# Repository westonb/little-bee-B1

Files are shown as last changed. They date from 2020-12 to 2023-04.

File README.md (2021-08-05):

# Little Bee B1 - A high performance current & magnetic field probe
**Operating Instructions are located in the [getting-started](getting-started/README.md) folder**

The Little Bee B1 is an open source magnetic field and current probe based on an Anisotropic Magneto-Resistive (AMR) magnetic sensor.
It directly senses magnetic fields and measures current with a current sensing attachment consisting of a gapped ferrite toroid that is placed around a wire, establishing a fixed relation between the current in the wire and magnetic field the sensor is subject to.

The probe is capable of sensing DC currents and has a high frequency -3dB bandwidth in excess of 10Mhz. Typical specifications for current sensing are a +/- 5A range, and a 3mA RMS noise floor. For magnetic field sensing the probe has a +/- 6 gauss range. It is compatible with any 1M ohm input oscilloscope and is powered by a single AA battery. The probe uses a PIC microcontroller to automatically zero the sensor and to provide adjustable gain and bandwidth.

All project source files are in this repository and the project currently has a CrowdSupply [campaign](https://www.crowdsupply.com/weston-braun/little-bee)
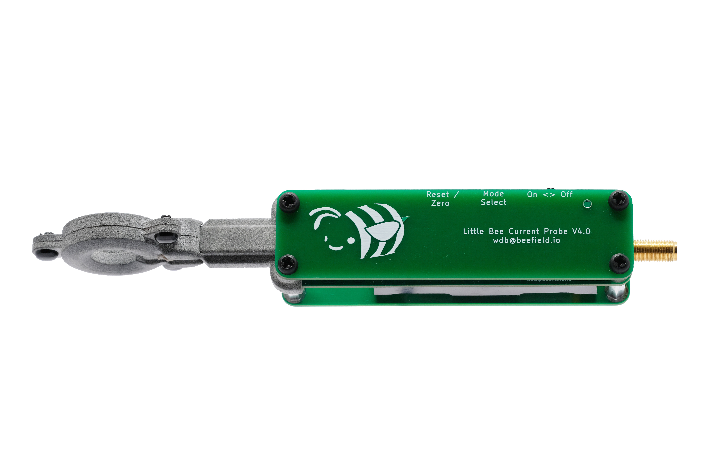
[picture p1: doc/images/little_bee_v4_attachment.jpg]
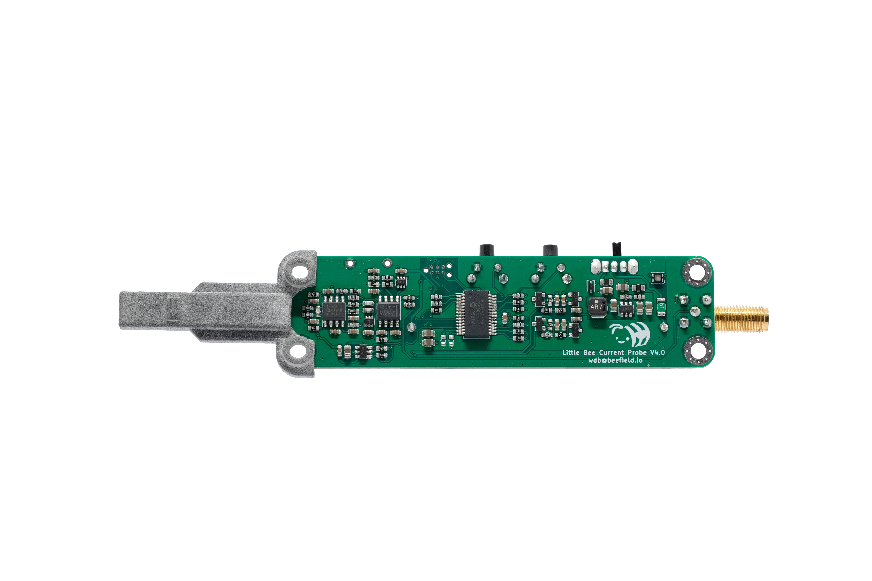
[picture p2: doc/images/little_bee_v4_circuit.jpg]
 

### Typical Electrical Performance

#### Current sensing

- **Bandwidth**: DC - 10 MHz
- **Sensitivity**: 0.25 Volts/Amp
- **Max Current**: +/- 5 A
- **Noise**
    - 3 mA RMS at 10 MHz bandwidth
    - 2 mA RMS at 1 MHz bandwidth
- **DC Accuracy**: +/- 15%
- **Insertion Impedance**: 100 nH in parallel with 70 Ohms

#### Magnetic Field Sensing

- **Bandwidth**: DC - 10 MHz
- **Sensitivity**: 0.2 Volts/Gauss
- **Max Field**: +/- 6 Gauss
- **Noise**
    - 4mG RMS at 10 MHz bandwidth
    - 2.5mG RMS at 1 MHz bandwidth

## Operation
Connect the Little Bee to any oscilloscope with a SMA-BNC cable. When the probe is powered on it automatically zeros and starts in the high bandwidth and low gain mode. Tapping the "Mode Select" button will cycle through the bandwidth and gain options, which are indicated by the LED color.

The probe should be re-zeroed after switching modes. This is accomplished by pressing and holding the "zero/reset" button for at least one second before releasing. The LED will blink once when the button is first pressed and a second time when the zeroing operation is done.

When the sensor is exposed to an excessive magnetic field, or excessive current when the current sensing attachment is used, the sensor will be demagnetized and need to be reset for normal operation. For on axis fields the probe can detect this and will turn the indicator light red.
Off axis fields, which can occur when the probe is used for magnetic field sensing, can exceed the sensor limit without being detected. This will result a loss of sensitivity and noticeable distortion in the sensed waveforms.  
The sensor can be reset and normal operation restored without impacting the zeroing of the probe by tapping the "zero/reset" button, which will briefly flash the indicator light.

If the probe senses a low battery that will inhibit normal operation the indicator light will flash red. An alkaline AA battery should provide around 4 hours of battery life.

### Current Sensing
Current sensing is achieved with the current sensing attachment, which clips on to the tip of the probe. The current sensing attachment uses a ferrite core to translate the current flowing in to a wire into a known magnetic field strength.
A wire can be threaded through the current sensing attachment or the current sensing attachment can be slipped over a wire before being clipped on. With the logo and writing on the Little Bee facing the user, a wire carrying current away from the user will be read as a positive current.

The location of the wire within the current sensing attachment has some impact on the sensitivity of the probe due to the magnetic field in generates. It is recommended to keep the wire on the opposite side of the sensing tip within the aperture of the current sensing attachment.

For higher resolution when measuring low currents, multiple turns of the wire can be made through the aperture of the current sensing attachment. The final sensitivity will be the set sensitivity times the number of turns.

Tapping the "Mode Select" button will cycle through the bandwidth and gain options, which are indicated by the LED color:

| LED Color | Mode |
|---|---|
| Green | 10MHz bandwidth 0.25V/A |
| Yellow | 1MHz bandwidth 0.25V/A  |
| Blue | 10MHz bandwidth 1V/A |
| Teal | 1MHz Bandwidth 1V/A |

The gain of the probe can be adjusted with the labeled trimmer resistor on the PCB. Units are shipped calibrated to the above gains.

### Magnetic Field Sensing
The magnetic sensor is located approximately 1.0mm offset from the tip of the probe. The Little Bee will measure a magnetic field entering perpendicular to the top of the probe as a positive voltage. To measure the magnetic field emitted by a PCB trace the probe should be placed perpendicular to the PCB with the long direction of the tip parallel to the trace.

The earth's magnetic field is typically between 0.3 - 0.6 Gauss, depending on geographic location. This is well within the sensing range of the probe. Additionally, large ferrous objects and transformers can emit stray magnetic fields. It is recommended the Little Bee is zeroed while holding it in the orientation used for taking measurements to reduce the error introduced by stray magnetic fields.

The gain of the probe is calibrated based on measurements with the current sensing attachment, so the true sensitivity will depend on the tolerance current sensing attachment. The nominal sensitivities are:

| LED Color | Mode |
|---|---|
| Green | 10MHz bandwidth 0.2 V/Gauss  |
| Yellow | 1MHz bandwidth 0.2 V/Gauss |
| Blue | 10MHz bandwidth 0.8 V/Gauss  |
| Teal | 1MHz Bandwidth 0.8 V/Gauss |

## Hardware
The kicad PCB files are in the [PCB](pcb/) directory and the [schematic](doc/current-sense.pdf) is in the doc directory.

## Firmware
The Little Bee uses a PIC16 microcontroller to automatically zero the probe and control gain and bandwidth switching. The firmware is built with the
MPLAB X IDE and the complete project is in the [firmware](firmware) directory

## Open Source
This work is licensed under a
[Creative Commons Attribution-ShareAlike 4.0 International License][cc-by-sa].

[][cc-by-sa]

[cc-by-sa]: http://creativecommons.org/licenses/by-sa/4.0/
[cc-by-sa-image]: https://licensebuttons.net/l/by-sa/4.0/88x31.png
[cc-by-sa-shield]: https://img.shields.io/badge/License-CC%20BY--SA%204.0-lightgrey.svg

## Demos
### Sensing the AC line current into a switch-mode power supply


### Sensing the magnetic field from an inductor


### Example Waveforms
Yellow Waveform: Little Bee B1

Green Waveform: Tektronix CT-2 Current Transformer
#### Ramp
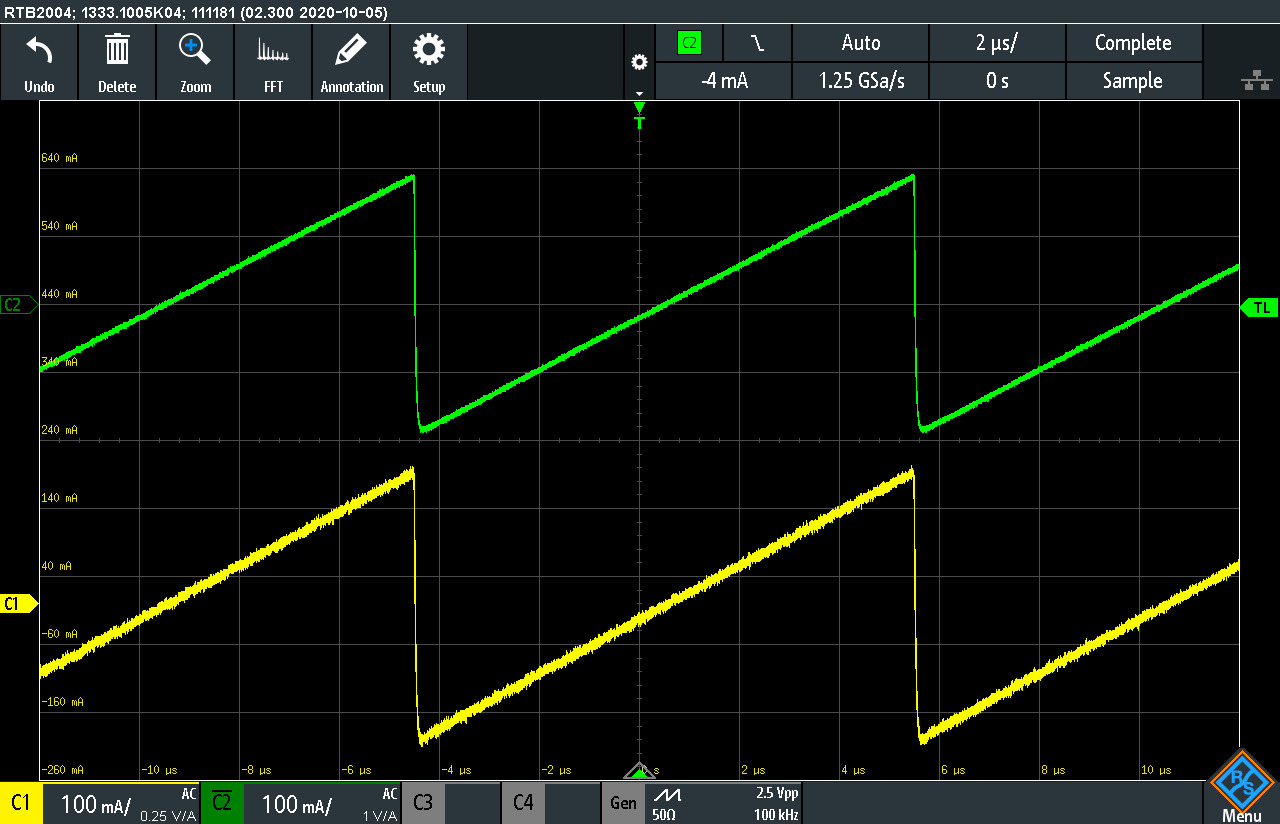
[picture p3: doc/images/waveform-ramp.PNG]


#### SinC
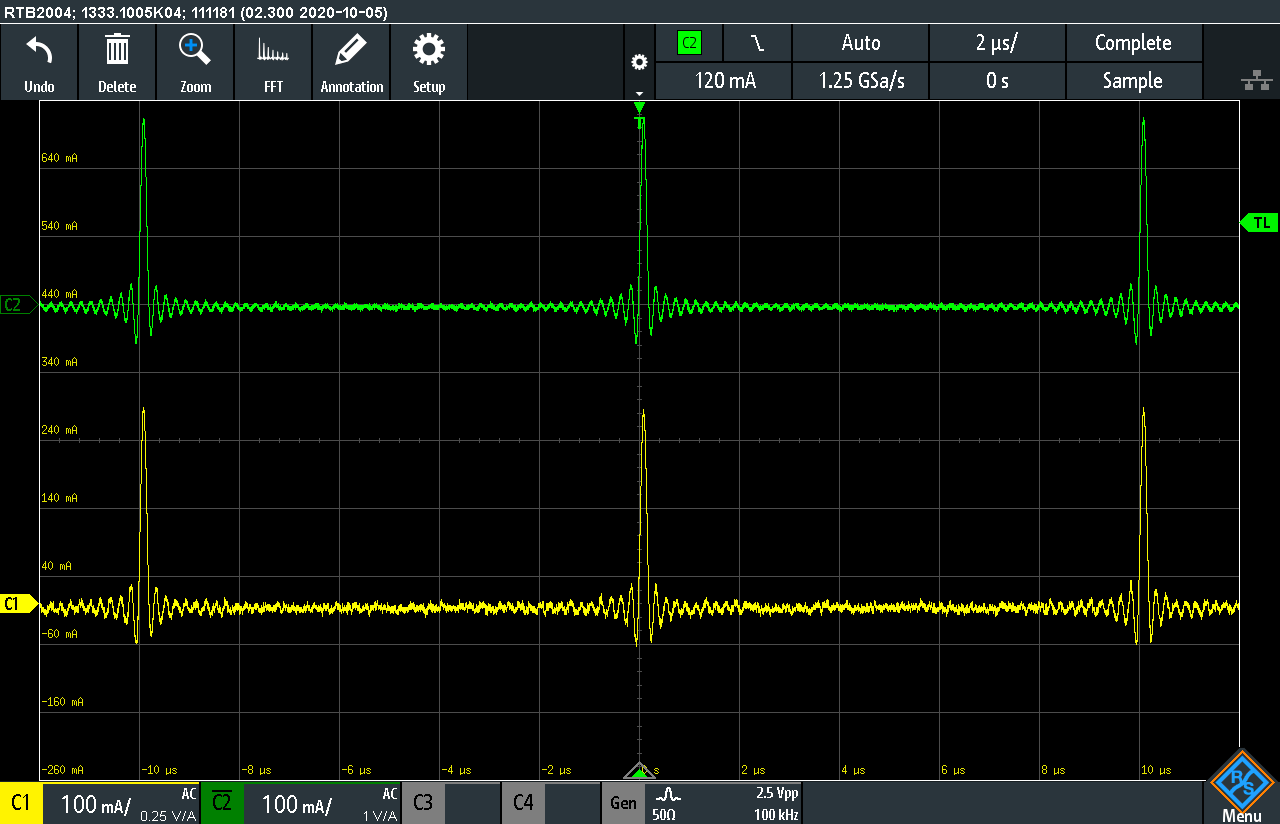
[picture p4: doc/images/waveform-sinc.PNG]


#### Square Wave (Low Current)
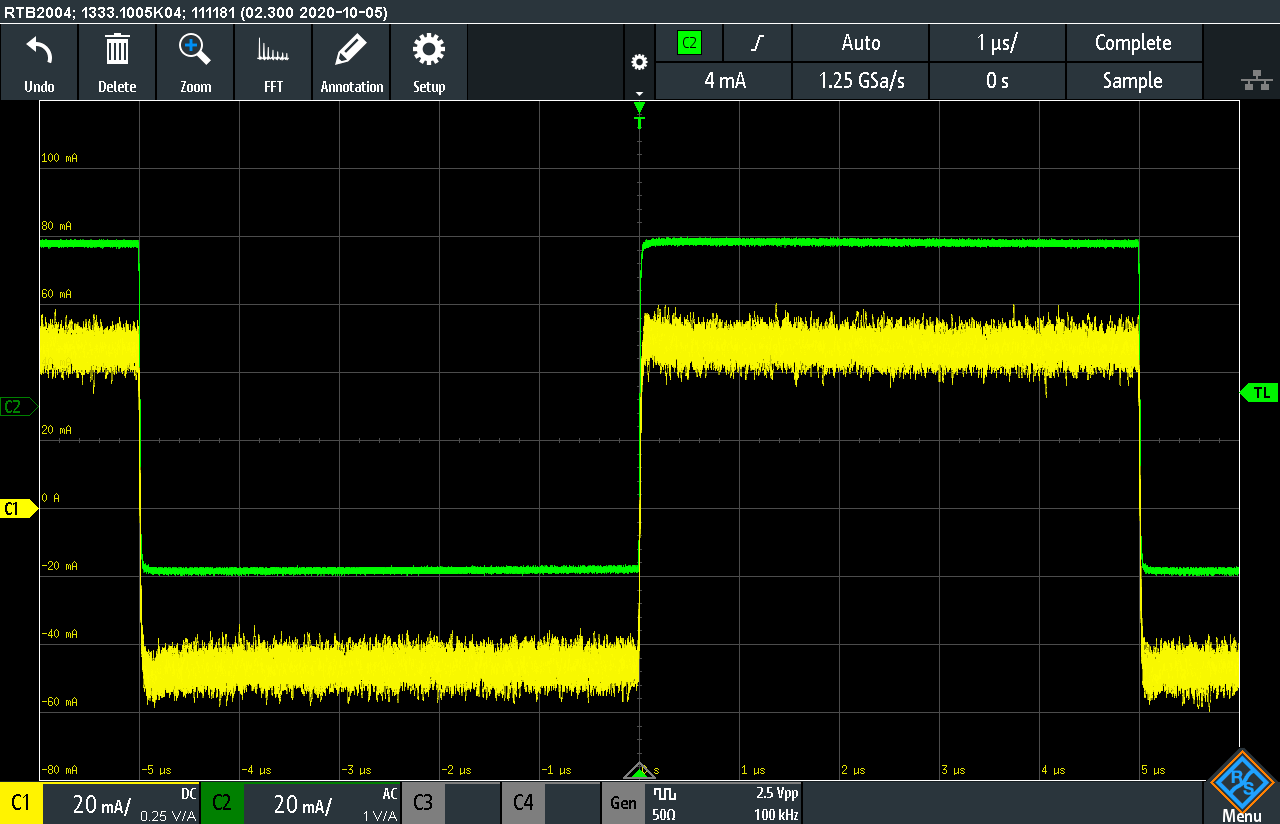
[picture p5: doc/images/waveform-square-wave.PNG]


#### Noise Floor
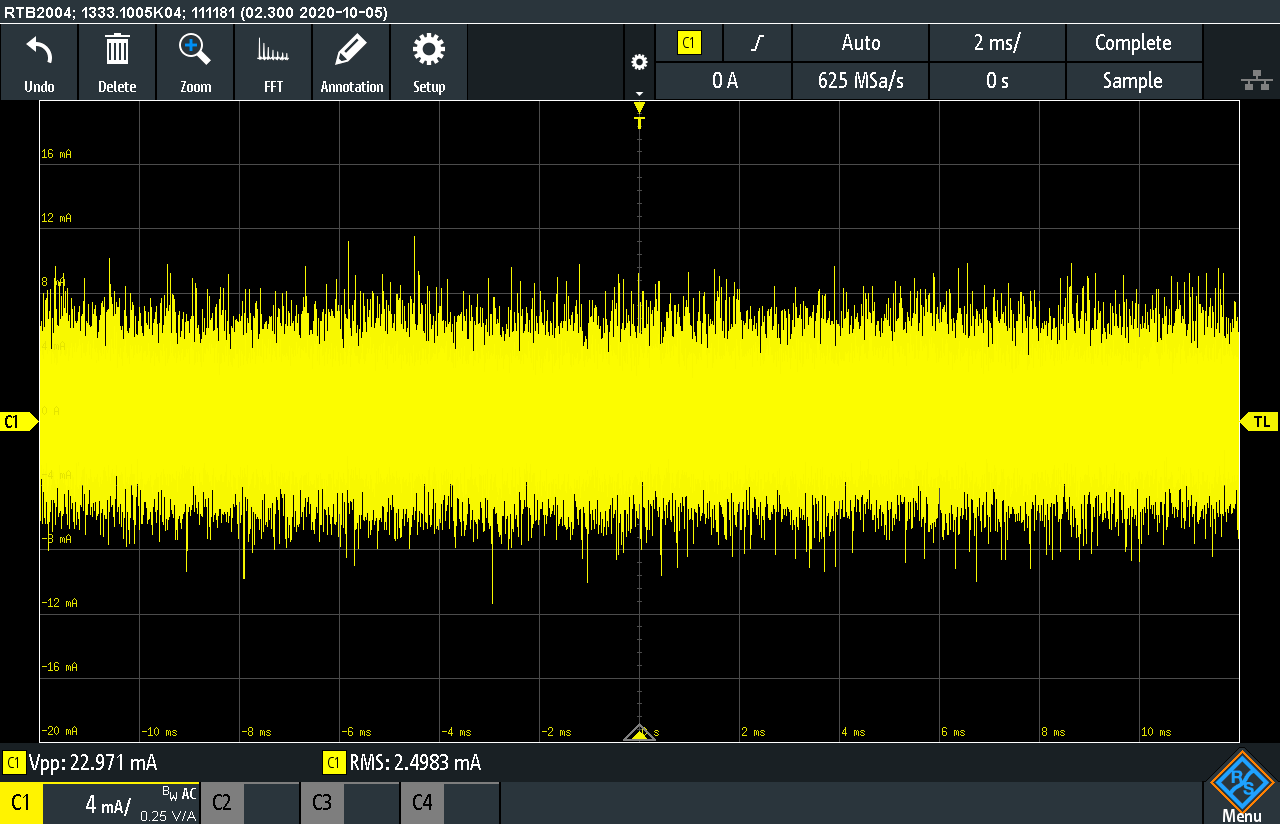
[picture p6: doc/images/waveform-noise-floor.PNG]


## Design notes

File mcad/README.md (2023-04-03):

# Mechanical Parts
Finished probe uses 2x of the ring cover STL and 1x of the tip cover. 
Bottom PCB cover is held in place with 4x M3-16 threaded standoffs. 
Top PCB cover is held in place with 2x 5mm OD 4mm long unthreaded standoffs.

# Flux Concentrator 
Fair-Rite 5943001301 core with a nominal gap of 8.25mm and parallel faces. Ring cover held into place with 3x 0.122" hole size plastic rivets, McMaster-Carr P/N 91020A120

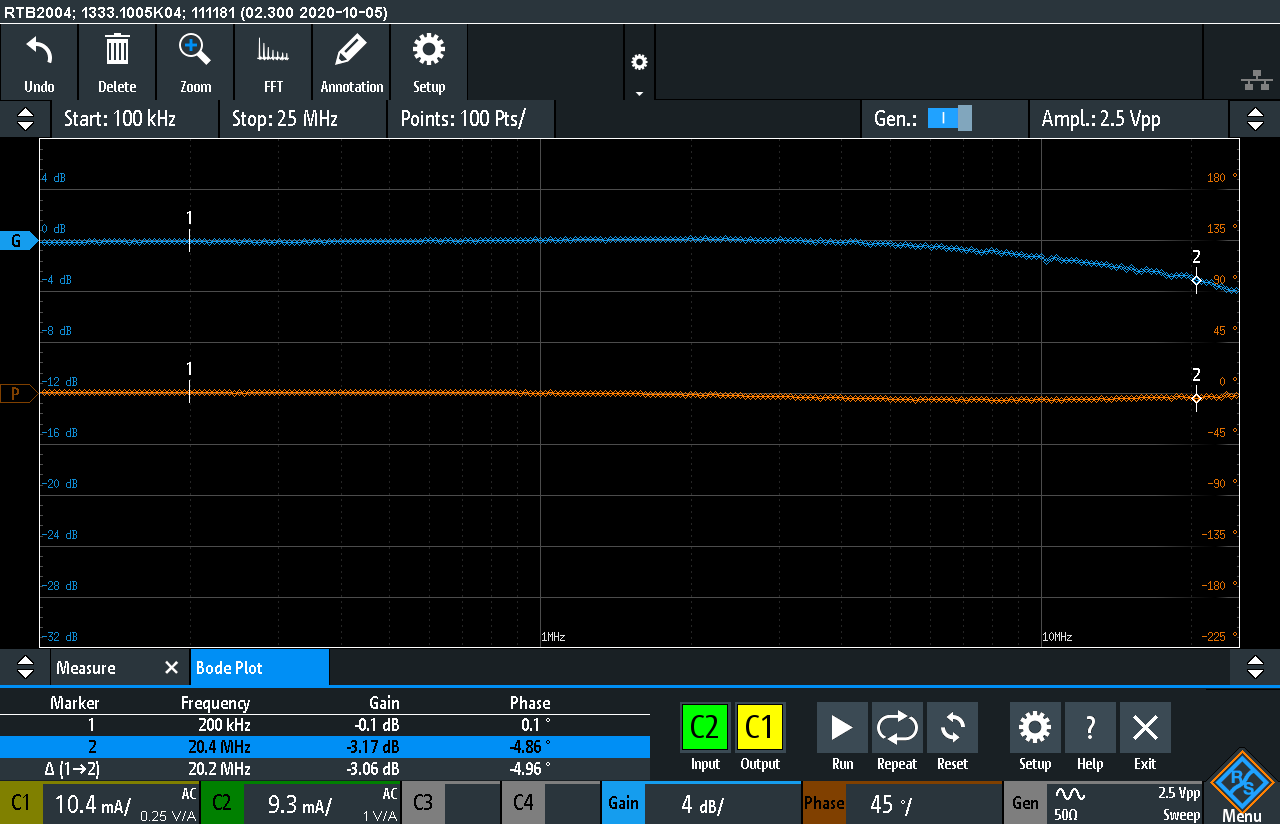
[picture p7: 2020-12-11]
doc/images/bode-highBW-low-gain.PNG

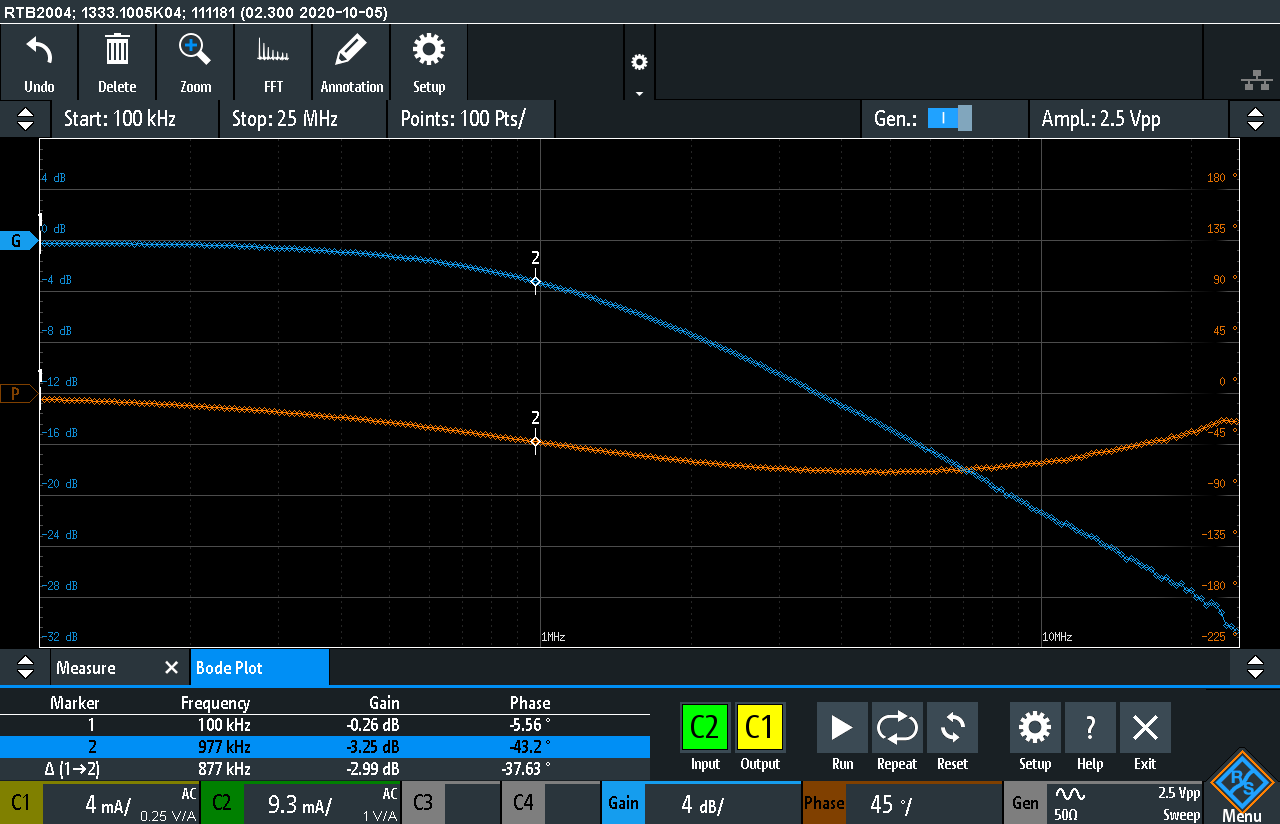
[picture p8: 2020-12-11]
doc/images/bode-lowBW-low-gain.PNG

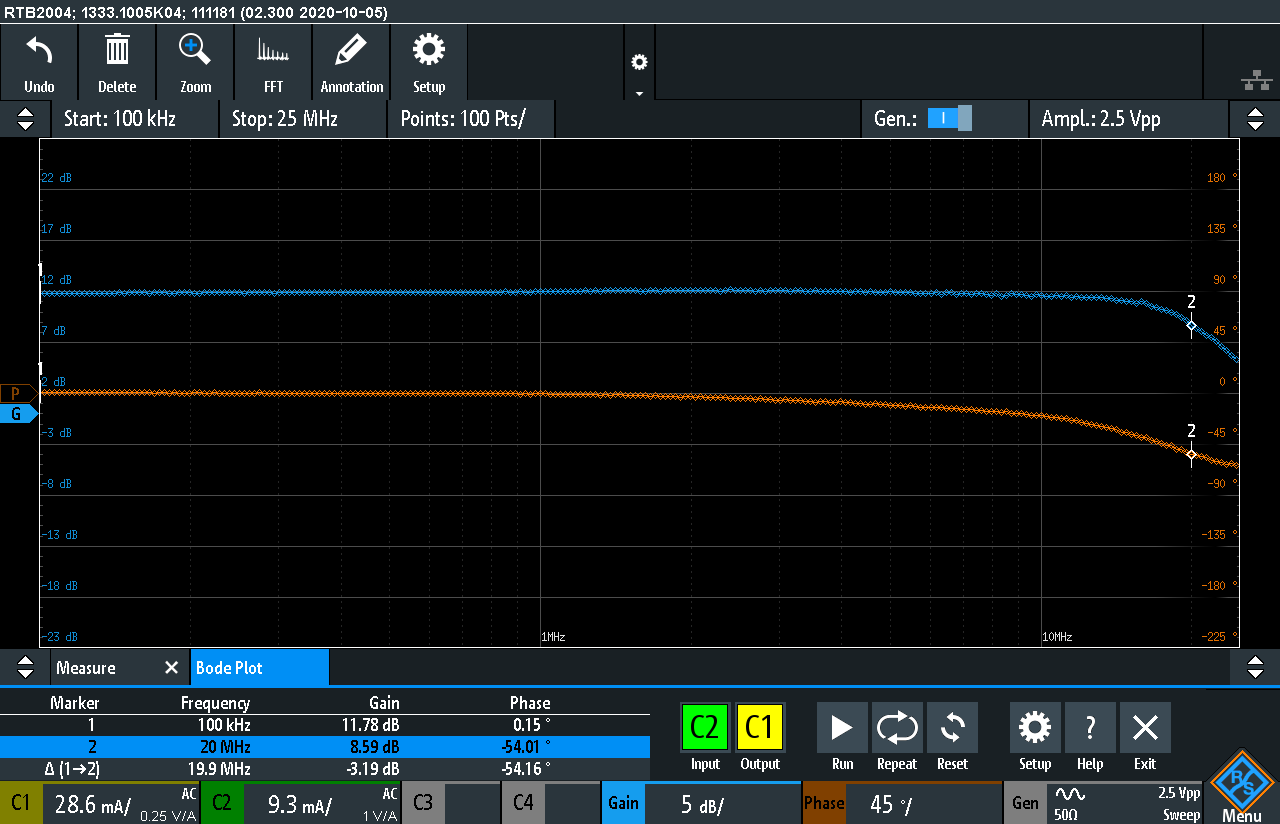
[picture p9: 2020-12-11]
doc/images/bode-highBW-high-gain.PNG

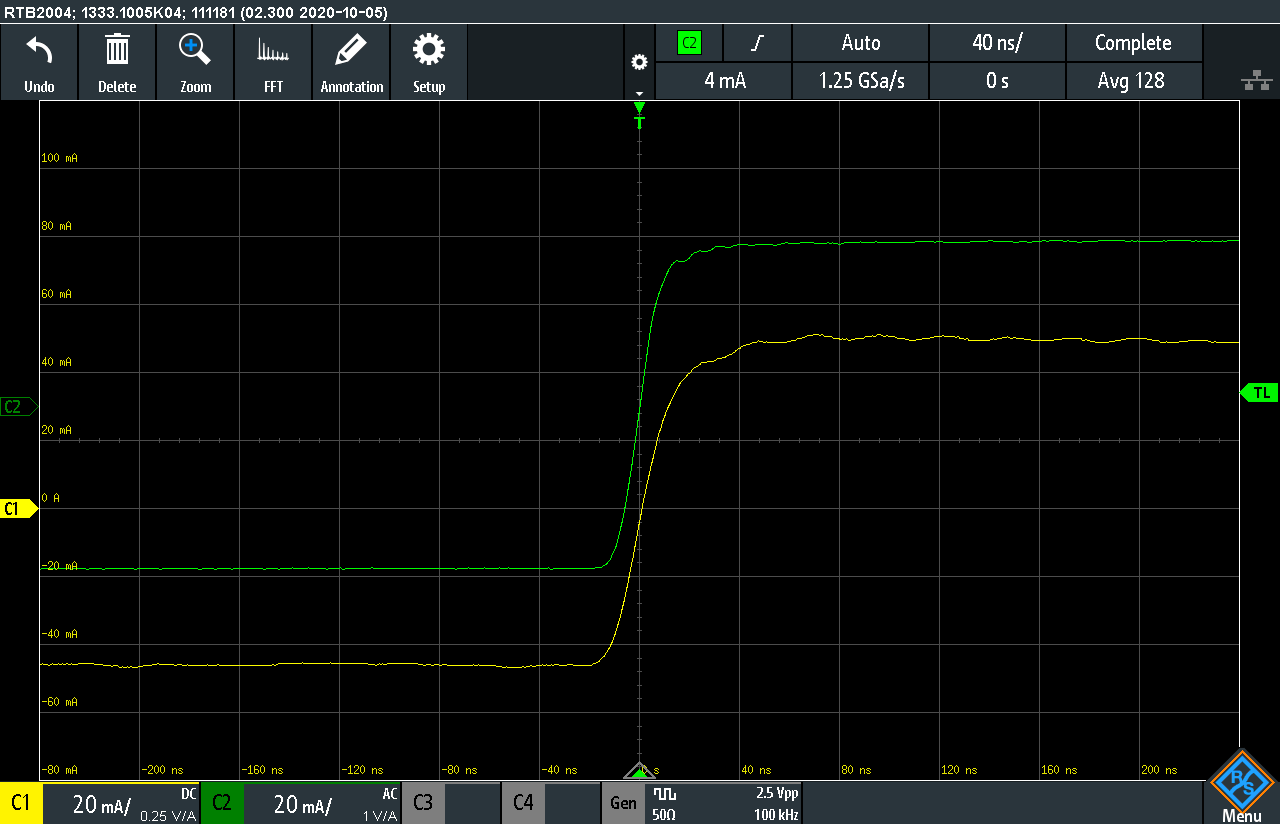
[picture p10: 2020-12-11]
doc/images/waveform-fast-edge.PNG

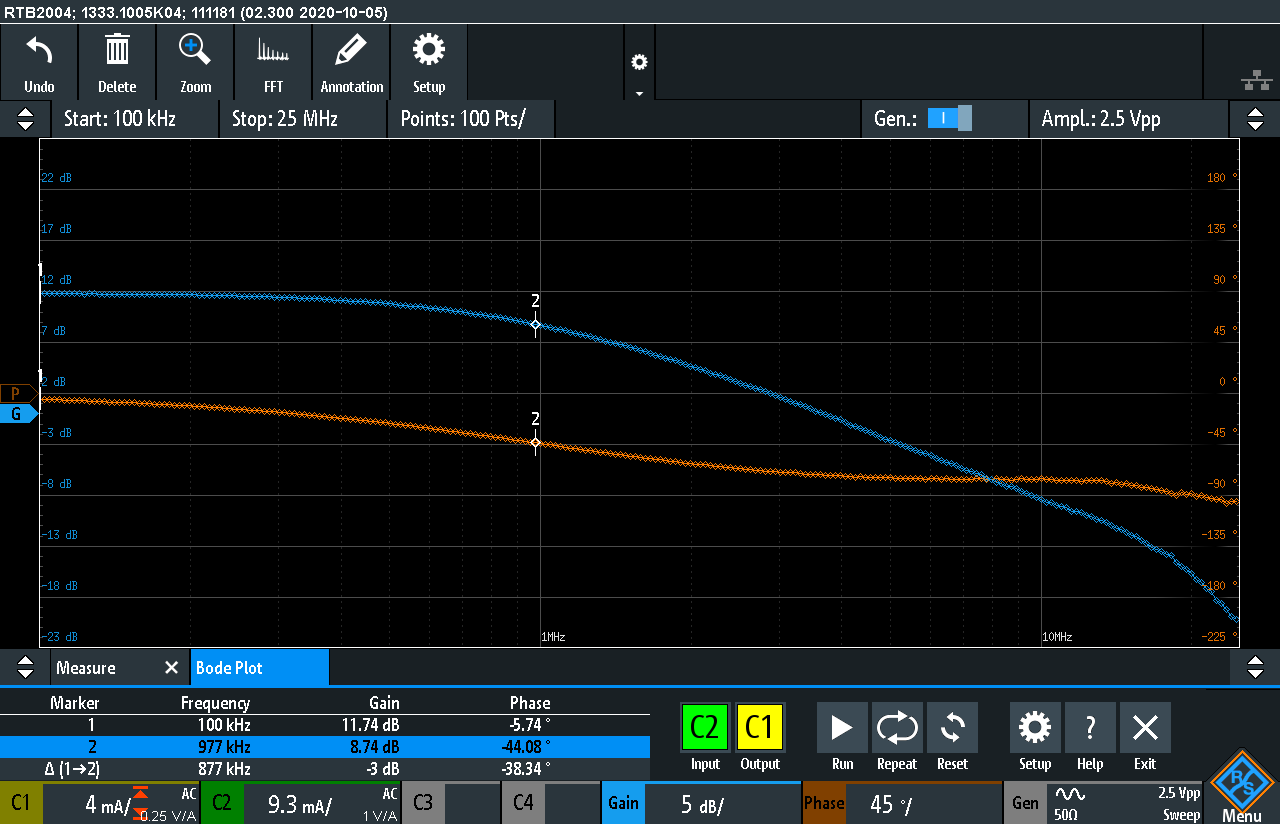
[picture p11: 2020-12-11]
doc/images/bode-lowBW-high-gain.PNG

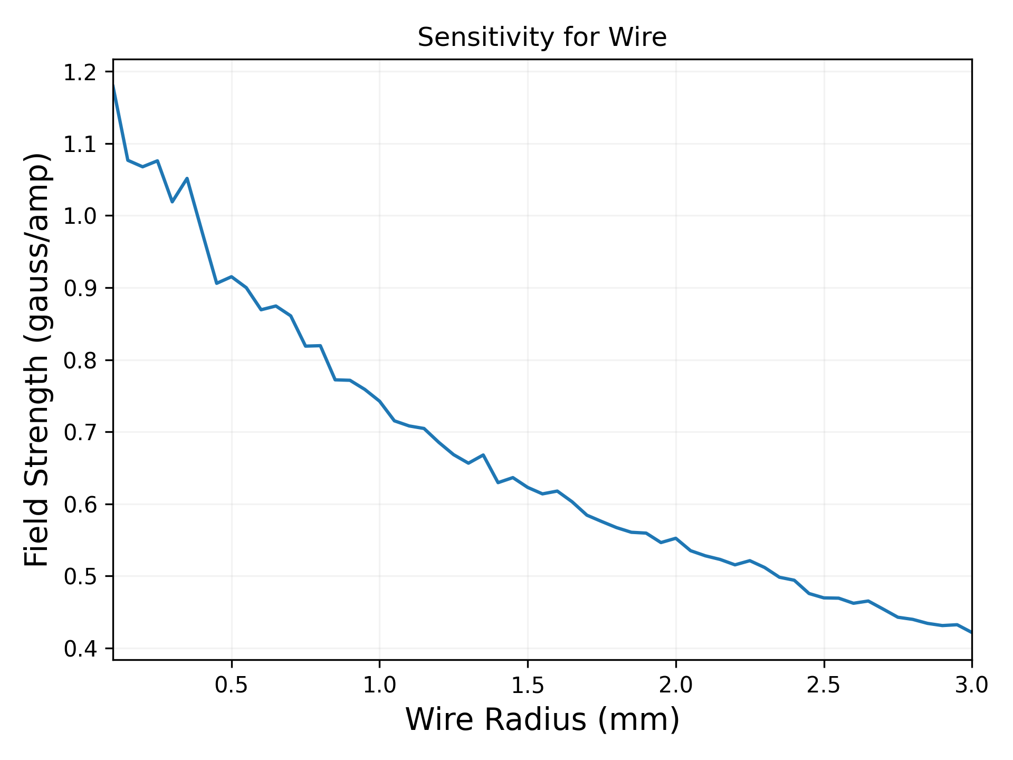
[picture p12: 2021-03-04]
modeling/wire_radius_plt.png

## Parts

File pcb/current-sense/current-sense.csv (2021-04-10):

Ref | Qty | Value | Footprint | Description | MPN
C1, C13, C14, C17, C20, C21, C22, C33, | 8 | 22u | Capacitor_SMD:C_0805_2012Metric | Unpolarized capacitor | LMK212BBJ226MG-T
C2, C3, C5, C8, C9, C10, C11, C12, C15, C16, C19, C23, C25, C26, C27, C28, C29, C30, C31, C32, C34, | 21 | 1u | Capacitor_SMD:C_0603_1608Metric | Unpolarized capacitor | CL10B105KO8NNNC
C4, | 1 | 10p | Capacitor_SMD:C_0603_1608Metric | Unpolarized capacitor | CL10C100CB8NNNC
C6, | 1 | 22p | Capacitor_SMD:C_0603_1608Metric | Unpolarized capacitor | CL10C220JB8NFNC
C7, | 1 | 750p | Capacitor_SMD:C_0603_1608Metric | Unpolarized capacitor | CC0603JRNPO9BN751
C18, C24, C35, C36, | 4 | DNP | Capacitor_SMD:C_0603_1608Metric | Unpolarized capacitor
D1, | 1 | LED_ARGB | LED_SMD:LED_Cree-PLCC4_2x2mm_CW | RGB LED, anode/red/green/blue | CLMVC-FKA-CL1D1L71BB7C3C3
D2, D3, | 2 | BAT54SLT1G | Package_TO_SOT_SMD:SOT-23 | Dual Schottky diode, anode/cathode/center | BAT54SLT1G
D4, | 1 | NTSAF345T3G | Diode_SMD:D_SMA | Diode | NTSAF345T3G
FB1, FB2, | 2 | Ferrite_Bead_Small | Inductor_SMD:L_0805_2012Metric | Ferrite bead, small symbol | BKP2125HS600-T
J1, J2, J4, J5, | 4 | M3 | wbraun_smd:M3-tight-fit-socket-head | mounting hole
J3, | 1 | Tag Connect | wbraun_smd:TC2030-IDC-NL | Generic connector, double row, 02x03, odd/even pin numbering scheme (row 1 odd numbers, row 2 even numbers), script generated (kicad-library-utils/schlib/autogen/connector/)
J6, | 1 | Conn_Coaxial | Connector_Coaxial:SMA_Molex_73251-2200_Horizontal | coaxial connector (BNC, SMA, SMB, SMC, Cinch/RCA, ...) | 619540-1
J7, | 1 | AA Holder | wbraun_smd:AA-2460 | Generic connector, single row, 01x02, script generated (kicad-library-utils/schlib/autogen/connector/) | 2460
J8, | 1 | DNP | Connector_JST:JST_XH_B2B-XH-A_1x02_P2.50mm_Vertical | Generic connector, single row, 01x02, script generated (kicad-library-utils/schlib/autogen/connector/) | B2B-XH-A(LF)(SN)
L1, | 1 | 4.7u | wbraun_smd:L_VLCF4020 | Inductor | VLCF4020T-4R7N1R2
NT1, | 1 | Net-Tie_2 | wbraun_smd:NET_TIE | Net tie, 2 pins
Q1, | 1 | FDC6327C | Package_TO_SOT_SMD:TSOT-23-6 | 4.6A/-3.2A Id, 20V Vds, Complementary pair enhancement mode P-Channel and N-Channel MOSFET, TSOT-23-6 | FDC6327C
R1, R2, R10, R11, R23, R24, R25, R27, R28, | 9 | 4.7k | Resistor_SMD:R_0603_1608Metric | Resistor | RC0603FR-074K7L
R3, R7, | 2 | 105 | Resistor_SMD:R_0603_1608Metric | Resistor | RC0603FR-07105RL
R4, R13, | 2 | 220 | Resistor_SMD:R_0603_1608Metric | Resistor | RC0603FR-07220RL
R5, R6, R20, | 3 | 43 | Resistor_SMD:R_0603_1608Metric | Resistor | RC0603FR-0743RL
R8, R9, R12, R15, R17, R19, | 6 | 1.43k | Resistor_SMD:R_0603_1608Metric | Resistor | RC0603FR-071K43L
R14, R22, R32, R33, R34, R35, R40, | 7 | 32.4k | Resistor_SMD:R_0603_1608Metric | Resistor | RC0603FR-0732K4L
R16, | 1 | 470 | Resistor_SMD:R_0603_1608Metric | Resistor | RC0603FR-07470RL
R18, | 1 | 0 | Resistor_SMD:R_0603_1608Metric | Resistor | RC0603JR-070RL
R21, | 1 | 102k | Resistor_SMD:R_0603_1608Metric | Resistor | RMCF0603FT102K
R26, R36, R37, | 3 | 4.7 | Resistor_SMD:R_0603_1608Metric | Resistor | RC0603FR-074R7L
R29, R38, R39, | 3 | DNP | Resistor_SMD:R_0603_1608Metric | Resistor
R30, R31, | 2 | 130 | Resistor_SMD:R_0603_1608Metric | Resistor | RC0603FR-07130RL
RV1, | 1 | 2k | wbraun_smd:TRIMMER_PVG3A | Trim-potentiometer, US symbol | PVG3A202C01R00
SW1, SW2, | 2 | SW_Push | wbraun_smd:SW_Tactile_SPST_Angled_PTS645Vx58-2LFS | Push button switch, generic, two pins | PTS645VL58-2 LFS
SW3, | 1 | SW_SPDT | wbraun_smd:SW_EG1247_SPDT_Angled | Switch, single pole double throw | EG1247
U1, | 1 | HMC1041Z | wbraun_smd:HMC1041Z | AMR Magnetic Sensor | HMC1041Z-TR
U2, | 1 | AD8129 | Package_SO:SOIC-8_3.9x4.9mm_P1.27mm | Differential Receiver | AD8129ARZ
U3, U6, | 2 | TMUX1219 | Package_TO_SOT_SMD:SOT-363_SC-70-6 | SPDT Analog Switch | TMUX1219DCKR
U4, | 1 | PIC16F1776-ISS | Package_SO:SSOP-28_5.3x10.2mm_P0.65mm | PIC Microcontroller | PIC16F1776-I/SS
U5, | 1 | TLV3542 | Package_SO:SOIC-8_3.9x4.9mm_P1.27mm |  | TLV3542IDR
U7, | 1 | MCP1640 | Package_TO_SOT_SMD:SOT-23-6 |  | MCP1640BT-I/CHY
U8, U9, | 2 | LM4041LP-ADJ | Package_TO_SOT_SMD:SOT-23 | Adjustable Precision Micropower Shunt Voltage Reference, TO-92 | LM4041CYM3-ADJ-TR

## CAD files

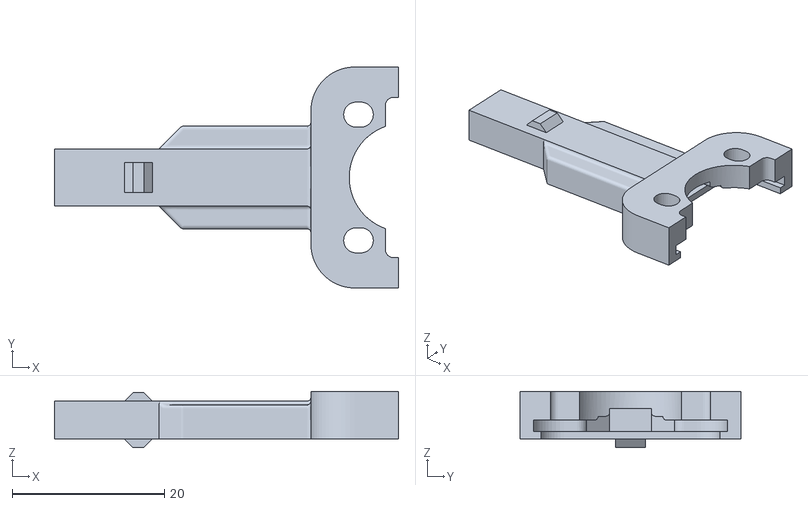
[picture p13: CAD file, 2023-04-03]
mcad/tip-cover_production.stl
45.2 x 29.0 x 7.35

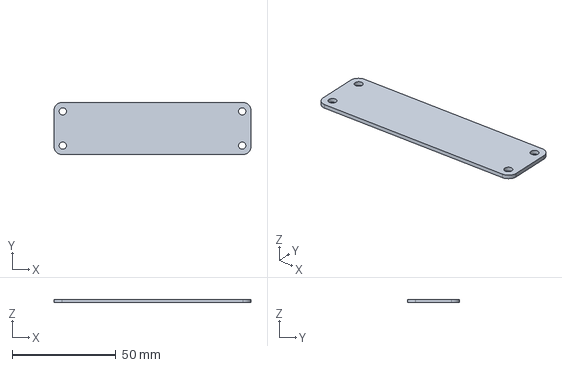
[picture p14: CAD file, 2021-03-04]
pcb/casing_bottom/casing.step
95.0 x 25.0 x 1.60 mm

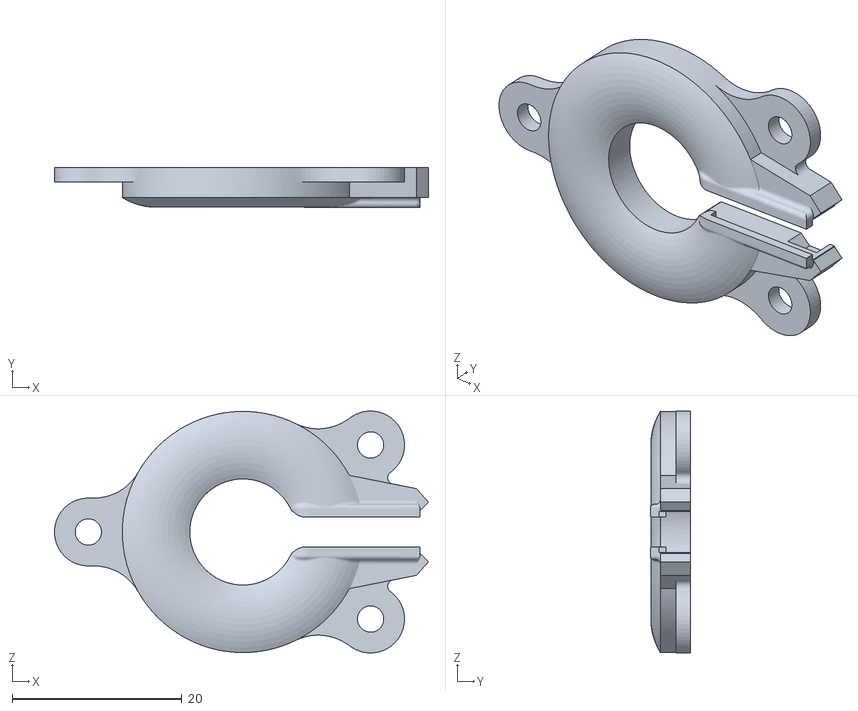
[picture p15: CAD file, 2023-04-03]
mcad/ring_cover_production.stl
44.1 x 4.75 x 28.5

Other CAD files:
pcb/casing_top/casing.step
mcad/casing_top.step

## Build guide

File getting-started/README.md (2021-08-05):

# Little Bee B1 Operating Instructions

## Introduction
The Little Bee is a current and magnetic field probe using an Anisotropic Magneto-Resistive (AMR) magnetic sensor.
Current in a wire can accurately be sensed in a wire with the current sensing attachment.
Without the attachment the Little Bee can be used to directly measure magnetic fields. In the context of circuit debugging this can be used to measure the current waveforms in PCB traces and inductors.  
The Little Bee is powered by a AA battery, with an expected battery life of 4 hours, and connects to any oscilloscope with a 1M Ohm input with a SMA to BNC cable.
The Little Bee has auto zeroing functionality and 4 different gain and bandwidth modes.

## Typical Electrical Performance
All Little Bee units are serialized and the frequency response is characterized in production for the low gain and 10MHz bandwidth mode.
Production data is in the [test-data](../production/test-data) folder in this repo.
Below is a plot of all of the production data.
The outliers are from early production where gain was adjusted after characterization and there was a 20MHz bandwidth limit enabled on the test oscilloscope.
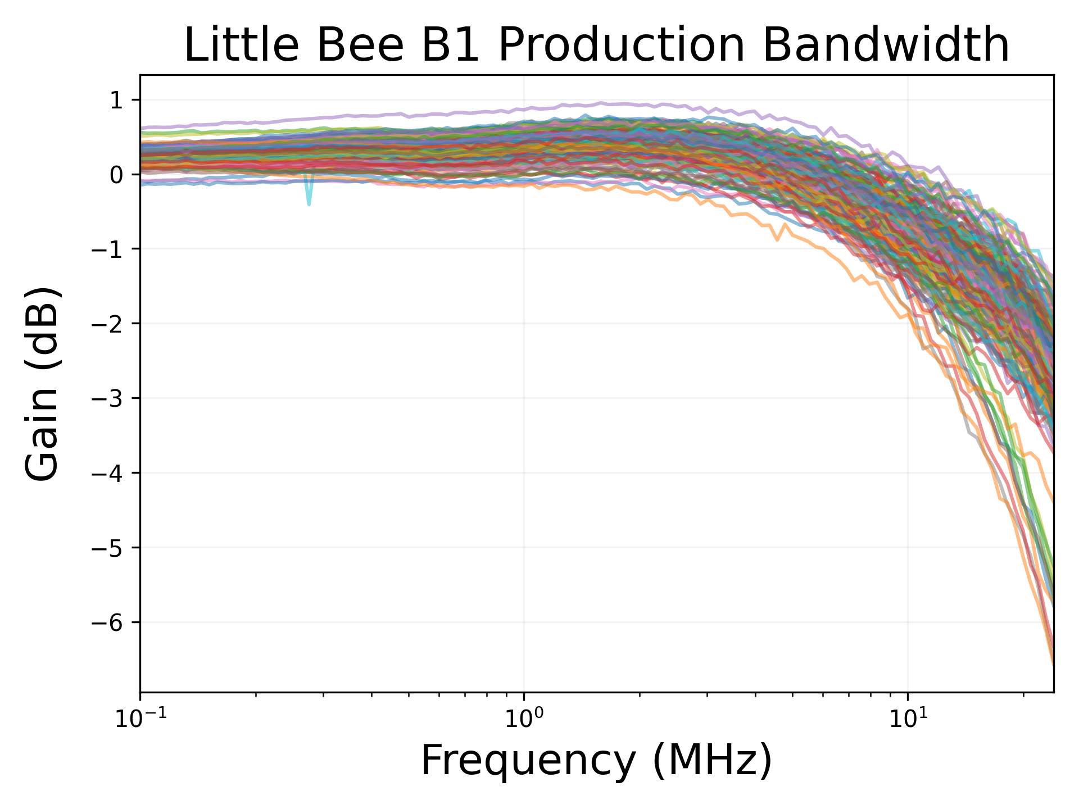
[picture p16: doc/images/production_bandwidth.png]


#### Current sensing

- **Bandwidth**: DC - 10 MHz
- **Sensitivity**: 0.25 Volts/Amp at low gain, 1.00 Volts/Amp at high gain
- **Max Current**: +/- 5 A at low gain, +/- 1.5 A at high gain
- **Noise**
    - 3 mA RMS at 10 MHz bandwidth
    - 2 mA RMS at 1 MHz bandwidth
- **DC Accuracy**: +/- 15%
- **Insertion Impedance**: 100 nH in parallel with 70 Ohms

#### Magnetic Field Sensing

- **Bandwidth**: DC - 10 MHz
- **Sensitivity**: 0.2 Volts/Gauss at low gain, 0.8 Volts/Gauss at high gain
- **Max Field**: +/- 6 Gauss at low gain, +/- 1.8 Gauss at high gain
- **Noise**
    - 4mG RMS at 10 MHz bandwidth
    - 2.5mG RMS at 1 MHz bandwidth

## Operation
### Start Up
When the Little Bee is powered on it will initialize in the low gain and high bandwidth mode and immediately enter the auto-zero routine.
The auto-zero routine takes 3.5 seconds and the LED will blink once when auto-zeroing is finished.
During this period the Little Bee will not respond to repeated button presses.
Once the auto-zero routine is done the Little Bee is ready to use.
The two buttons "Reset/Zero" and "Mode Select" are used to control the functionality of the Little Bee and the color of the status LED is used to indicate the probe status and operating mode.
By holding both buttons down before power is switched on the Little Bee will start up in an absolute field sensing mode until power is cycled.

### Reset and Zero
The "Reset/Zero" button can be used to reset the sensor after exposure to a high magnetic field or to zero the probe in order to remove impacts from ambient magnetic fields for improved accuracy when measuring low currents or magnetic fields.
Tapping the "Reset/Zero" button will reset the sensor.
When the sensor is reset the status LED will flash off and on twice in quick succession.
If the status LED was previously red due to the requirement for a sensor reset, the status LED will return to the normal color after reset.
Resetting the Little Bee sensor has no impact on the zeroing.  

If the "Reset/Zero" button is held for more than 1 second the probe will enter the auto-zero routine, which takes 2 to 4 seconds.
The LED will flash off and on once at the start of the auto-zero routine and once after the auto-zero routine is finished.

Rarely, the auto-zero routine is unable to zero the output due to high ambient magnetic fields.
When this happens the status LED will blink red at the end of the auto-zeroing routine.

### Mode Select
Pressing the "Mode Select" button cycles the Little Bee through the 4 gain and bandwidth modes.
The current mode is indicated by the color of the status LED.
The status LED will cycle in the order of  \[Green, Yellow, Blue, Teal\]  with each press of the "Mode Select" button.

### Status LED
The status LED is used to indicate the gain and bandwidth setting of the Little Bee as well as to indicate error conditions.
The below table details the meaning of each status LED color.

| Status LED Color | Mode |
|---|---|
| Green | 10MHz bandwidth 0.25V/A or 0.2 V/Gauss |
| Yellow | 1MHz bandwidth 0.25V/A or 0.2 V/Gauss |
| Blue | 10MHz bandwidth 1V/A or 0.8 V/Gauss |
| Teal | 1MHz Bandwidth 1V/A or 0.8 V/Gauss |
| Red | Sensor Reset Required |
| Flashing Red | Low Battery |
| Purple | Absolute Field Sensing Mode |

### Current Sensing



The Little Bee is used for current sensing mode by clipping the included current sensing attachment on to the detents on the probe tip and passing a wire though the hole in the current sensing attachment.
To reduce mechanical strain it is recommended to hold the Little Bee by the plastic tip cover when clipping on the current sensing attachment.

The electrical operation of the Little Bee is the same between current sensing and field sensing, the current sensing attachment merely establishes a fixed relationship between the current flowing in the wire and the magnetic field the sensor is exposed to.
The direction of current flow in a wire for a positive output voltage is indicated on the top of the Little Bee.

The location of the wire within the current sensing attachment may cause minor changes in the gain of the probe.
For maximal accuracy it is recommended to prevent the wire from being directly adjacent to the probe tip and instead keep it centered in the middle or at the far end of the current sensing attachment.
When measuring small currents, multiple turns of wire may be made through the center of the current sensing attachment to increase the response.
The current measured by the Little Bee will be the current flowing through the wire multiplied by the number of turns.

The current sensing attachment may have a residual magnetic field and only reduces, but does not eliminate, the influences of external magnetic fields.
To maximize accuracy it is recommended to zero the Little Bee after clipping the current sensing attachment on and placing the Little Bee as part of the test setup.

The magnetic domains in the AMR sensor used in the Little Bee can be mis-aligned by large magnetic fields, leading to incorrect output until the sensor is reset.
With the current sensing attachment, the majority of the magnetic field will be on the sensitive axis of the sensor, which allows the Little Bee to detect this overload condition.
At currents above 6 amps the status LED will turn red, indicating the need for a sensor reset.

### Magnetic Field Sensing



Without the current sensing attachment the Little Bee can be used to directly sense magnetic fields.
Useful applications for this include tracing currents in PCB traces and measuring inductor current waveforms through leakage magnetic fields.
The magnetic field direction for a positive output voltage is marked on the top of the Little Bee and shown below for convenience.

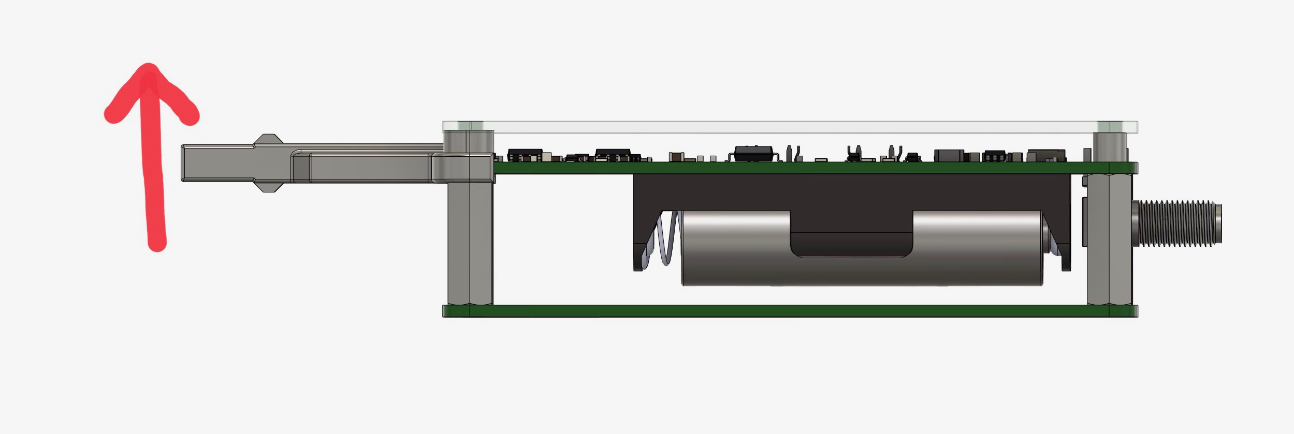
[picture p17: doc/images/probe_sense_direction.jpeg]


This direction means that for checking the current in a PCB trace the body of the Little Bee should be held perpendicular to the PCB with the longer side of the probe tip parallel to the PCB trace.
If trying to measure the current in a PCB trace it is recommended to first calibrate your measurements with a known current flowing through a PCB trace, but for typical PCB geometries the Little Bee response will be around 0.2V/A when the probe is in low gain mode.

Due to the small magnetic fields generated by PCB traces carrying even modest currents, measurements are susceptible to ambient magnetic fields, with the magnetic field strength of the earth being a large contributor.
It is recommended that measurements be taken away from any large iron transformers, motors, or fans, and the Little Bee first be zeroed while being held a few inches above the PCB in the orientation that will be used for probing.

Another difficulty in taking magnetic field measurements is saturating the sensor with excessive magnetic fields.
The sensor can be overloaded, corrupting the output until it is reset, by magnetic fields that are not on the sensitive axis.
This means that, unlike with current sensing, the Little Bee can not always detect when the sensor has been overloaded and requires a reset.
For applications where the magnetic field may be large and it is not necessarily clear what the magnetic field direction is, such as sensing the leakage magnetic fields of inductors and transformers, it is recommended to keep the Little Bee as far back as possible while still getting good readings and to reset the sensor often.

### Absolute Field Sensing Mode  
The absolute field sensing mode is mostly a novelty and debug tool that was added in late development.
If both buttons are held down when the Little Bee is turned on the system will enter absolute field sensing mode until power is cycled and the status LED will turn purple.
In this mode all further button inputs are ignored until power is cycled.

In this mode the sensor sensing polarity is flipped at 55Hz by re-aligning the magnetic domains using the reset circuitry.
This effectively performs signal mixing with the sensor input and a 55Hz signal.
This shifts the sensor DC magnetic field reading to 55Hz while all system offsets stay at DC, allowing the value of the absolute magnetic field strength to be measured as a peak to peak AC value.
This can be used for checking ambient magnetic field strengths, which would otherwise be zeroed out by the probe.
Additionally, with added digital signal processing, this mode can allow for the Little Bee to measure very small magnetic fields.

## Safety
The Little Bee B1 is not CAT rated.
Do not use the Little Bee on un-insulated wires.
The Little Bee is designed for use in a laboratory environment. 

## Improvements
### External Power
Based on user feedback to power the Little Bee with something other than a AA battery, there is an unpopulated footprint for a 2 pin JST-XH connector (part number B2B-XH-A(LF)(SN)).
Through this footprint up to 4.5 volts can be supplied, such as an lithium-ion battery.
If an external power adapter is used it must be low noise and isolated; the SMA ground terminal on the Little Bee is not directly referenced to the negative pin on this terminal.

### Mechanical Case
STL files for a user printable mechanical case for the Little Bee are under development.

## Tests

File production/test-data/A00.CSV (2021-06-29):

in Sa | Frequency in Hz | Gain in dB | Phase in ° | Amplitude in Vpp
1.00E+00 | 1.000E+05 | 2.587E-01 | 8.329E-01 | 2.500E+00
2.00E+00 | 1.047E+05 | 2.527E-01 | 8.043E-01 | 2.500E+00
3.00E+00 | 1.096E+05 | 2.648E-01 | 8.466E-01 | 2.500E+00
4.00E+00 | 1.148E+05 | 2.637E-01 | 9.053E-01 | 2.500E+00
5.00E+00 | 1.202E+05 | 2.644E-01 | 7.898E-01 | 2.500E+00
6.00E+00 | 1.259E+05 | 2.675E-01 | 9.241E-01 | 2.500E+00
7.00E+00 | 1.318E+05 | 2.888E-01 | 8.734E-01 | 2.500E+00
8.00E+00 | 1.380E+05 | 2.826E-01 | 8.632E-01 | 2.500E+00
9.00E+00 | 1.445E+05 | 2.929E-01 | 8.439E-01 | 2.500E+00
1.00E+01 | 1.514E+05 | 3.014E-01 | 8.783E-01 | 2.500E+00
1.10E+01 | 1.585E+05 | 3.076E-01 | 8.904E-01 | 2.500E+00
1.20E+01 | 1.660E+05 | 3.093E-01 | 9.422E-01 | 2.500E+00
1.30E+01 | 1.738E+05 | 3.088E-01 | 9.404E-01 | 2.500E+00
1.40E+01 | 1.820E+05 | 3.291E-01 | 7.872E-01 | 2.500E+00
1.50E+01 | 1.905E+05 | 3.288E-01 | 9.480E-01 | 2.500E+00
1.60E+01 | 1.995E+05 | 3.330E-01 | 9.495E-01 | 2.500E+00
1.70E+01 | 2.089E+05 | 3.522E-01 | 9.988E-01 | 2.500E+00
1.80E+01 | 2.188E+05 | 3.464E-01 | 1.001E+00 | 2.500E+00
1.90E+01 | 2.291E+05 | 3.365E-01 | 9.493E-01 | 2.500E+00
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

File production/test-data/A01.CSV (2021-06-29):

in Sa | Frequency in Hz | Gain in dB | Phase in ° | Amplitude in Vpp
1.00E+00 | 1.000E+05 | -9.074E-02 | -2.916E-01 | 2.500E+00
2.00E+00 | 1.047E+05 | -9.190E-02 | -2.077E-01 | 2.500E+00
3.00E+00 | 1.096E+05 | -8.761E-02 | -2.109E-01 | 2.500E+00
4.00E+00 | 1.148E+05 | -9.141E-02 | -2.560E-01 | 2.500E+00
5.00E+00 | 1.202E+05 | -8.684E-02 | -2.825E-01 | 2.500E+00
6.00E+00 | 1.259E+05 | -8.277E-02 | -2.794E-01 | 2.500E+00
7.00E+00 | 1.318E+05 | -7.945E-02 | -2.813E-01 | 2.500E+00
8.00E+00 | 1.380E+05 | -1.041E-01 | -3.073E-01 | 2.500E+00
9.00E+00 | 1.445E+05 | -9.230E-02 | -3.640E-01 | 2.500E+00
1.00E+01 | 1.514E+05 | -8.920E-02 | -3.247E-01 | 2.500E+00
1.10E+01 | 1.585E+05 | -8.069E-02 | -2.483E-01 | 2.500E+00
1.20E+01 | 1.660E+05 | -9.211E-02 | -3.403E-01 | 2.500E+00
1.30E+01 | 1.738E+05 | -1.092E-01 | -3.258E-01 | 2.500E+00
1.40E+01 | 1.820E+05 | -8.998E-02 | -3.476E-01 | 2.500E+00
1.50E+01 | 1.905E+05 | -1.050E-01 | -3.434E-01 | 2.500E+00
1.60E+01 | 1.995E+05 | -9.993E-02 | -4.127E-01 | 2.500E+00
1.70E+01 | 2.089E+05 | -9.892E-02 | -1.932E-01 | 2.500E+00
1.80E+01 | 2.188E+05 | -9.953E-02 | -3.078E-01 | 2.500E+00
1.90E+01 | 2.291E+05 | -9.226E-02 | -3.032E-01 | 2.500E+00
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

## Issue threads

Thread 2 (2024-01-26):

Schematic vs PCB error

ltwin8, 2024-01-26:
Could you please clarify which PCB version is the one in the gerbers?

I saw for example that https://github.com/westonb/little-bee-B1/blob/main/doc/images/little_bee_v4_circuit.jpg seems to be V4 (?) and switching the main current to the DCDC and has a PPTC before and a Ferrite after the switch, while in the schematic the switch is only used for the EN line.

I did not look further into it because i thought maybe its just an upload issue?

I really like the project and look forward to give it a try.

by the way, which Ferrite ring do i have to use? maybe mouser or digikey? and what geometry of the cut?

best regards

Alphaprot, 2025-08-27:
@ltwin8 Just a guess here: The portion of the picture you are describing sounds a lot like the schematic "current-sense.pdf", tagged "first release candidate", which is located in [pcb/current-sense/current-sense.pdf](https://github.com/westonb/little-bee-B1/blob/main/doc/current-sense.pdf).

Information regarding the ferrite ring and how to cut it can be found under [/mcad/README.md](https://github.com/westonb/little-bee-B1/blob/main/mcad/README.md). A multi tool's ("Dremel") cutting wheel can be used to make the cut accordingly (use at your own risk).

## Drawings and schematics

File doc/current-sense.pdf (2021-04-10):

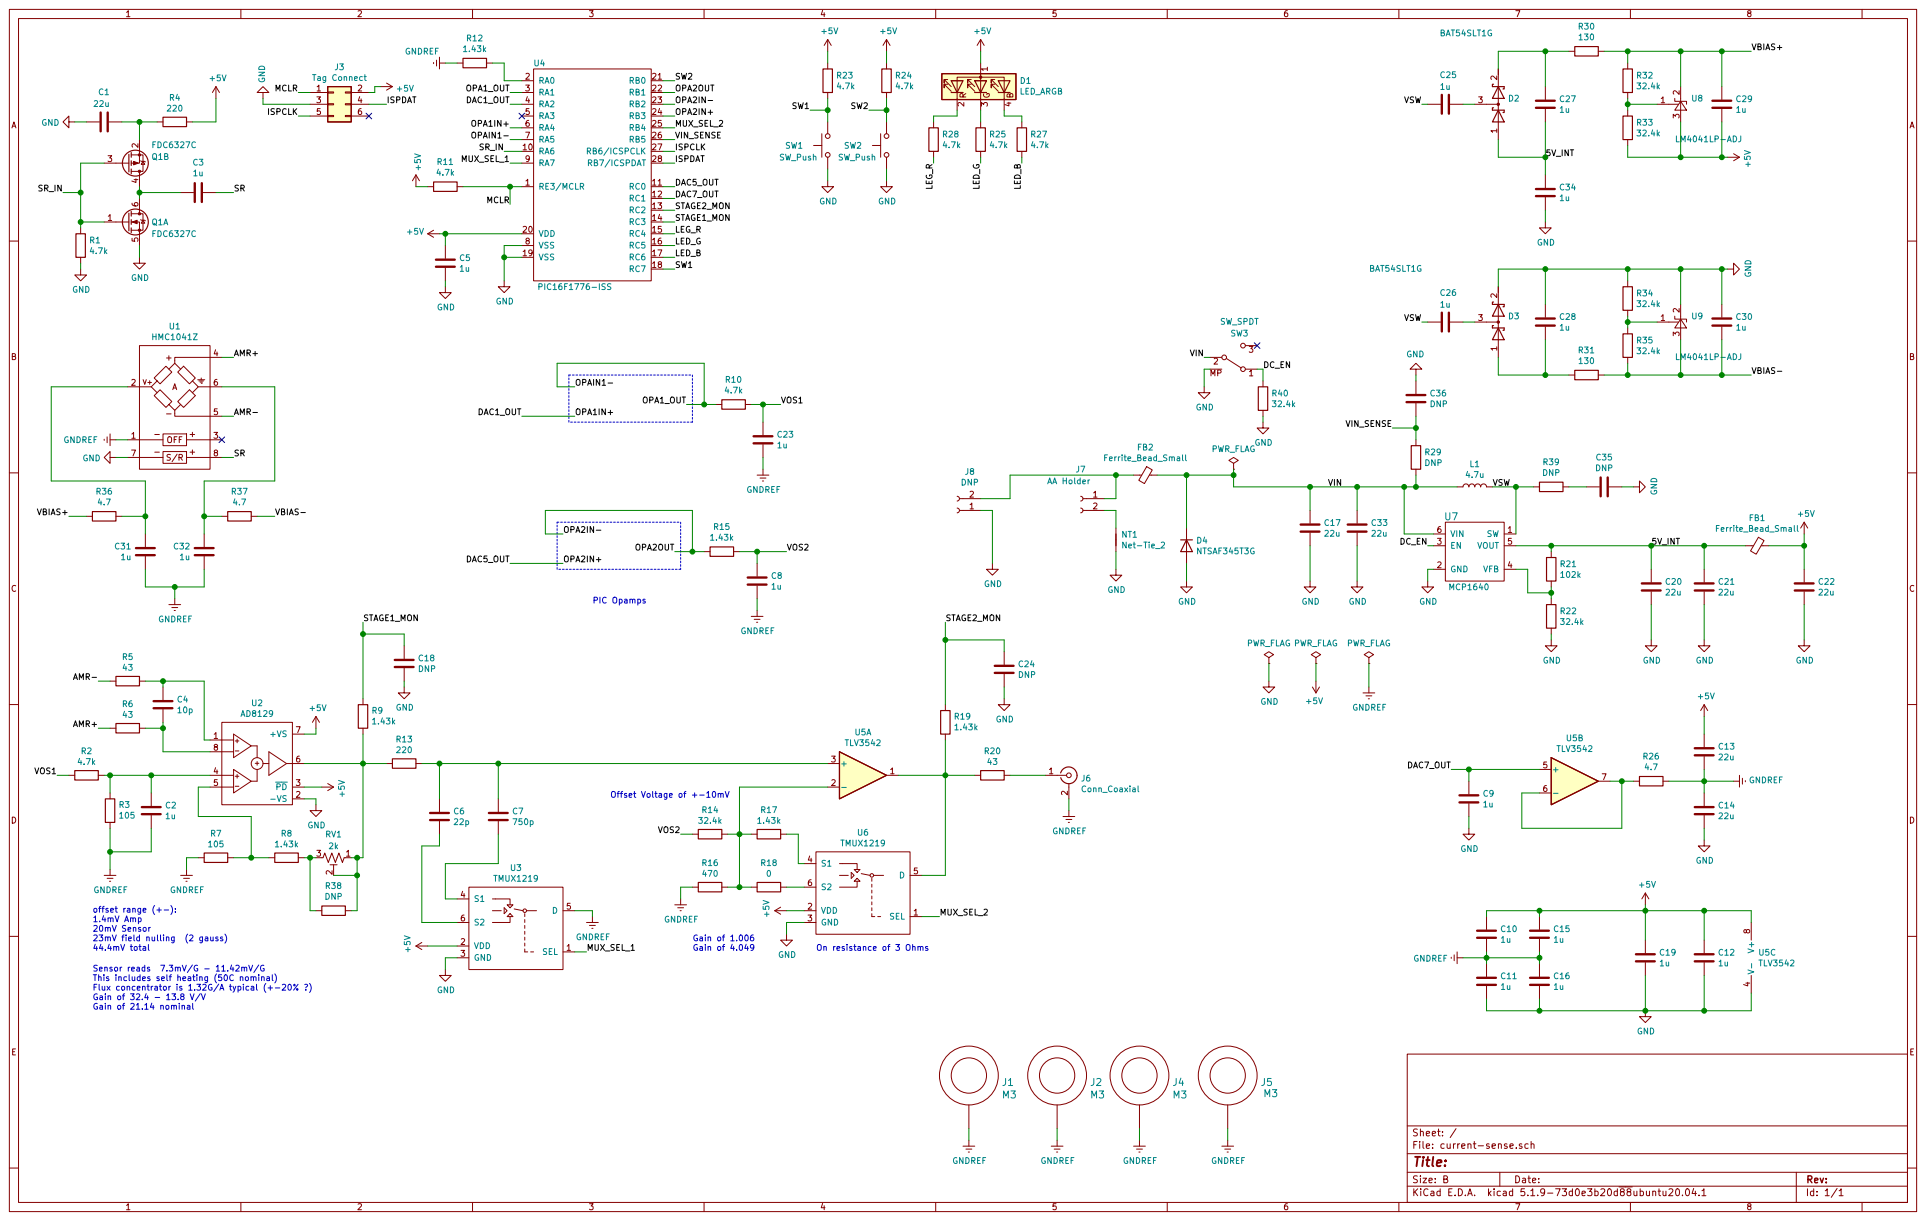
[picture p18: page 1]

Offset Voltage of +-10mVGain of 1.006 Gain of 4.049 Sensor reads 7.3mV/G - 11.42mV/G

1.4mV Amp
20mV Sensor 23mV field nulling (2 gauss) 44.4mV total

This includes self heating (50C nominal)

Id: 1/1 Title: File: current-sense.sch Sheet: /

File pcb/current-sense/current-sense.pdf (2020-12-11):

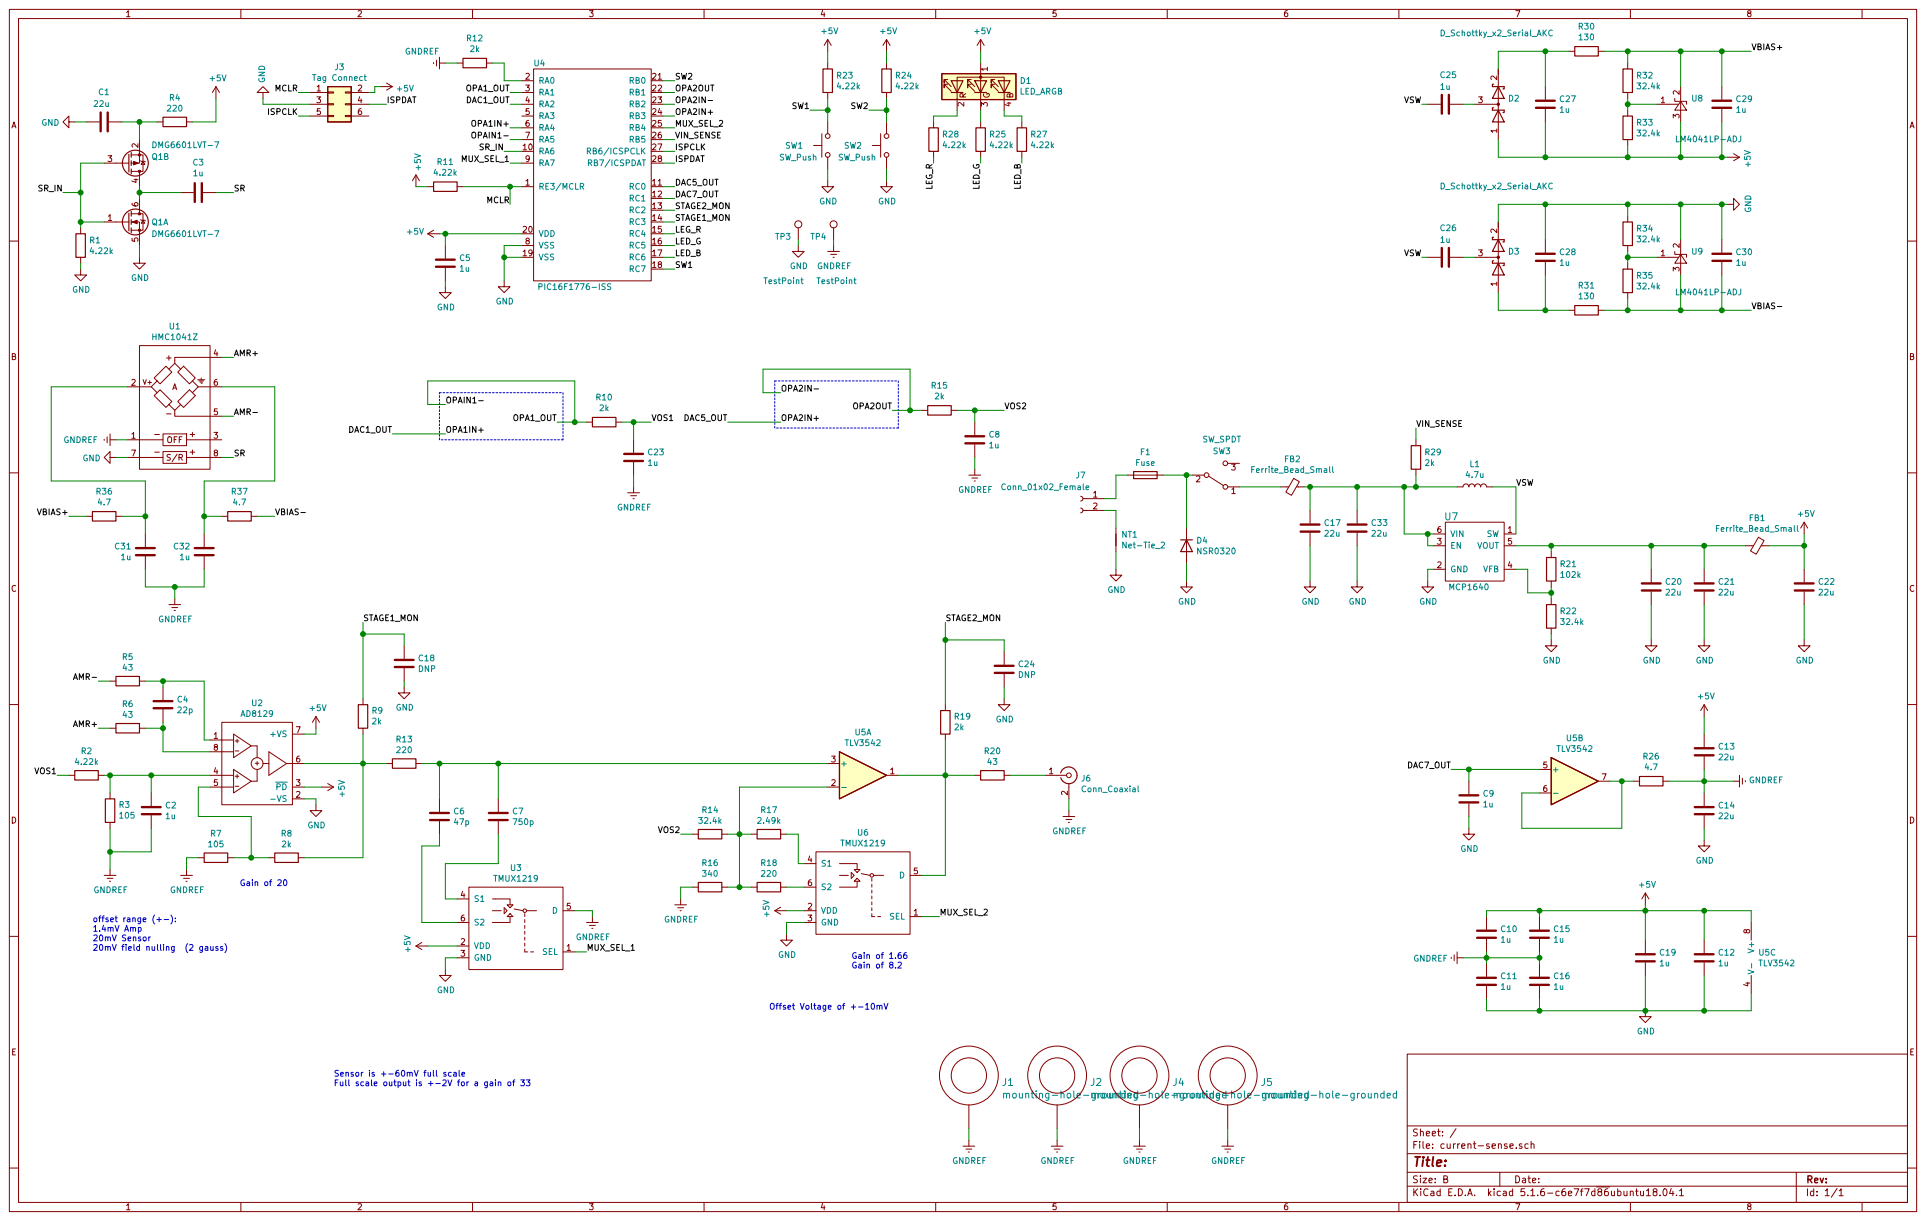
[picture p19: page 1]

Id: 1/1 Title: File: current-sense.sch Sheet: /

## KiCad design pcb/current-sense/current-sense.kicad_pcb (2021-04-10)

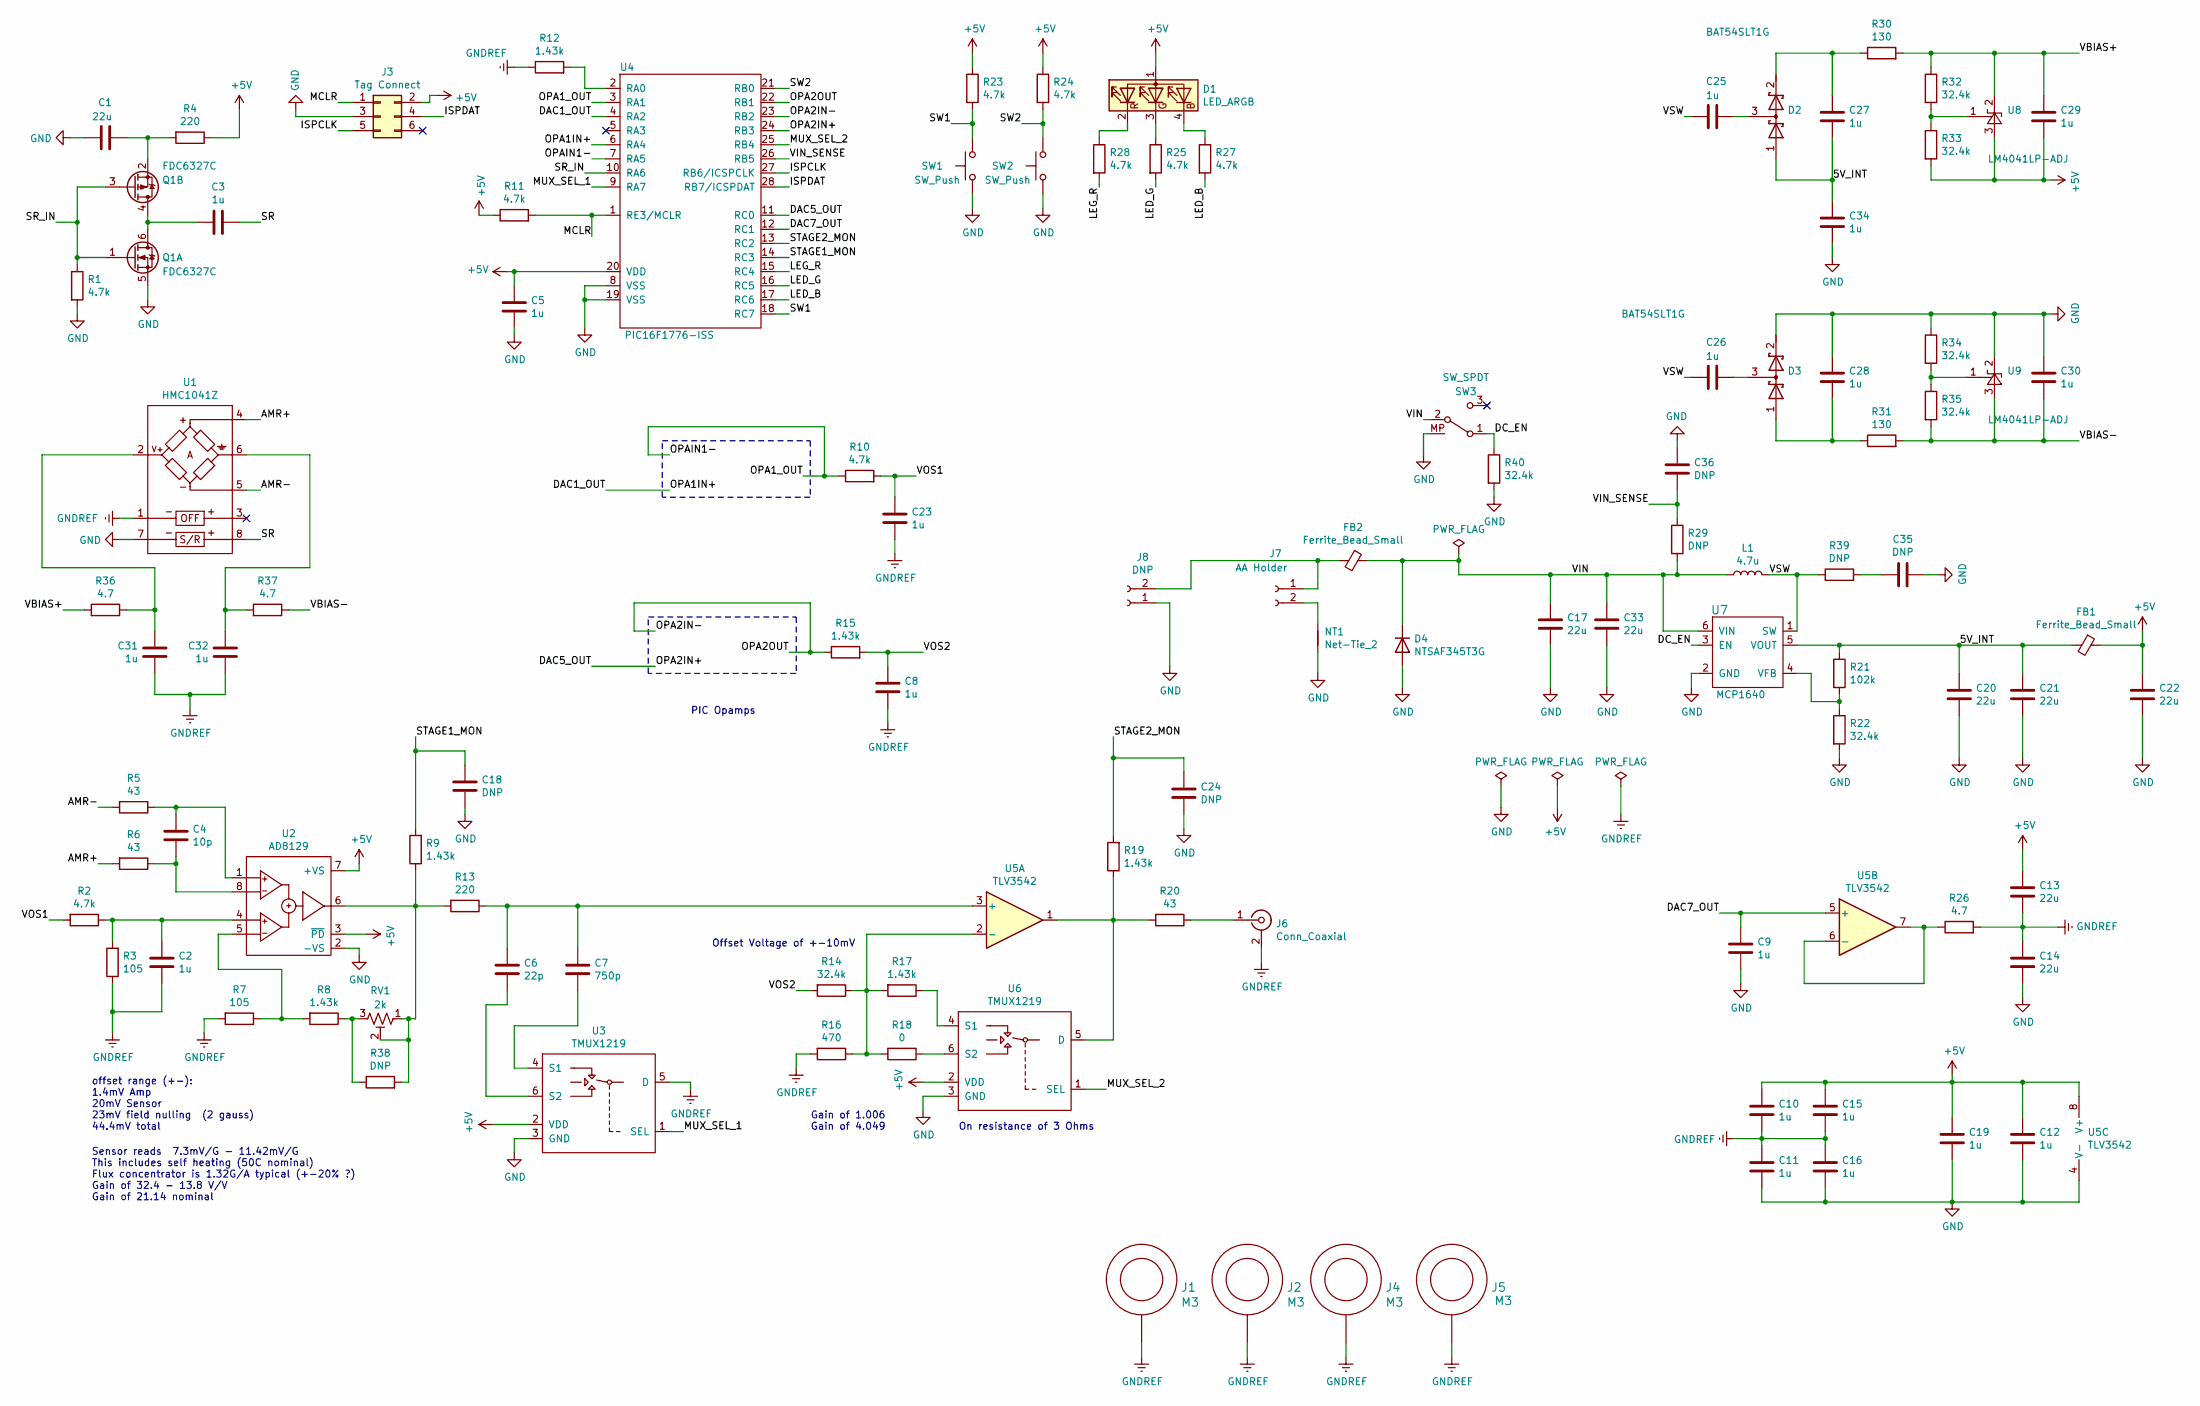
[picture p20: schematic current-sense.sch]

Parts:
C1, C13, C14, C17, C20, C21, C22, C33: 22u; C_0805_2012Metric; MPN LMK212BBJ226MG-T
C2, C3, C5, C8, C9, C10, C11, C12, C15, C16, C19, C23, C25, C26, C27, C28, C29, C30, C31, C32, C34: 1u; C_0603_1608Metric; MPN CL10B105KO8NNNC
C4: 10p; C_0603_1608Metric; MPN CL10C100CB8NNNC
C6: 22p; C_0603_1608Metric; MPN CL10C220JB8NFNC
C7: 750p; C_0603_1608Metric; MPN CC0603JRNPO9BN751
C18, C24, C35, C36: DNP; C_0603_1608Metric
D1: LED_ARGB; LED_Cree-PLCC4_2x2mm_CW; MPN CLMVC-FKA-CL1D1L71BB7C3C3
D2, D3: BAT54SLT1G; SOT-23; MPN BAT54SLT1G
D4: NTSAF345T3G; D_SMA; MPN NTSAF345T3G
FB1, FB2: Ferrite_Bead_Small; L_0805_2012Metric; MPN BKP2125HS600-T
J1, J2, J4, J5: M3; M3-tight-fit-socket-head
J3: Tag Connect; TC2030-IDC-NL
J6: Conn_Coaxial; SMA_Molex_73251-2200_Horizontal; MPN 619540-1
J7: AA Holder; AA-2460; MPN 2460
J8: DNP; JST_XH_B2B-XH-A_1x02_P2.50mm_Vertical; MPN B2B-XH-A(LF)(SN)
L1: 4.7u; L_VLCF4020; MPN VLCF4020T-4R7N1R2
NT1: Net-Tie_2; NET_TIE
Q1: FDC6327C; TSOT-23-6; MPN FDC6327C
R1, R2, R10, R11, R23, R24, R25, R27, R28: 4.7k; R_0603_1608Metric; MPN RC0603FR-074K7L
R3, R7: 105; R_0603_1608Metric; MPN RC0603FR-07105RL
R4, R13: 220; R_0603_1608Metric; MPN RC0603FR-07220RL
R5, R6, R20: 43; R_0603_1608Metric; MPN RC0603FR-0743RL
R8, R9, R12, R15, R17, R19: 1.43k; R_0603_1608Metric; MPN RC0603FR-071K43L
R14, R22, R32, R33, R34, R35, R40: 32.4k; R_0603_1608Metric; MPN RC0603FR-0732K4L
R16: 470; R_0603_1608Metric; MPN RC0603FR-07470RL
R18: 0; R_0603_1608Metric; MPN RC0603JR-070RL
R21: 102k; R_0603_1608Metric; MPN RMCF0603FT102K
R26, R36, R37: 4.7; R_0603_1608Metric; MPN RC0603FR-074R7L
R29, R38, R39: DNP; R_0603_1608Metric
R30, R31: 130; R_0603_1608Metric; MPN RC0603FR-07130RL
RV1: 2k; TRIMMER_PVG3A; MPN PVG3A202C01R00
SW1, SW2: SW_Push; SW_Tactile_SPST_Angled_PTS645Vx58-2LFS; MPN PTS645VL58-2 LFS
SW3: SW_SPDT; SW_EG1247_SPDT_Angled; MPN EG1247
U1: HMC1041Z; MPN HMC1041Z-TR
U2: AD8129; SOIC-8_3.9x4.9mm_P1.27mm; MPN AD8129ARZ
U3, U6: TMUX1219; SOT-363_SC-70-6; MPN TMUX1219DCKR
U4: PIC16F1776-ISS; SSOP-28_5.3x10.2mm_P0.65mm; MPN PIC16F1776-I/SS
U5: TLV3542; SOIC-8_3.9x4.9mm_P1.27mm; MPN TLV3542IDR
U7: MCP1640; SOT-23-6; MPN MCP1640BT-I/CHY
U8, U9: LM4041LP-ADJ; SOT-23; MPN LM4041CYM3-ADJ-TR

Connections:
+5V: C5.1, C10.1, C12.1, C13.1, C15.1, C19.1, C22.1, C29.2, D1.1 (A), FB1.1, J3.2, R4.1, R11.1, R23.1, R24.1, R33.2, U2.3 (~PD), U2.7 (+VS), U3.2 (VDD), U4.20 (VDD), U5.8 (V+), U6.2 (VDD), U8.3 (A)
/5V_INT: C20.1, C21.1, C27.2, C34.1, D2.1 (A), FB1.2, R21.1, U7.5 (VOUT)
/AMR+: R6.2, U1.4
/AMR-: R5.2, U1.5
/DAC1_OUT: U4.4 (RA2), U4.6 (RA4)
/DAC5_OUT: U4.11 (RC0), U4.24 (RB3)
/DAC7_OUT: C9.1, U4.12 (RC1), U5.5 (+)
/DC_EN: R40.1, SW3.1 (A), U7.3 (EN)
/ISPCLK: J3.5, U4.27 (RB6/ICSPCLK)
/ISPDAT: J3.4, U4.28 (RB7/ICSPDAT)
/LED_B: R27.2, U4.17 (RC6)
/LED_G: R25.2, U4.16 (RC5)
/LEG_R: R28.2, U4.15 (RC4)
/MCLR: J3.1, R11.2, U4.1 (RE3/MCLR)
/MUX_SEL_1: U3.1 (SEL), U4.9 (RA7)
/MUX_SEL_2: U4.25 (RB4), U6.1 (SEL)
/OPA1_OUT: R10.1, U4.3 (RA1), U4.7 (RA5)
/OPA2IN-: R15.1, U4.22 (RB1), U4.23 (RB2)
/SR: C3.2, U1.8
/SR_IN: Q1.1 (G), Q1.3 (G), R1.1, U4.10 (RA6)
/STAGE1_MON: C18.1, R9.2, U4.14 (RC3)
/STAGE2_MON: C24.1, R19.2, U4.13 (RC2)
/SW1: R23.2, SW1.1, U4.18 (RC7)
/SW2: R24.2, SW2.1, U4.21 (RB0)
/VBIAS+: C29.1, R30.2, R32.1, R36.2, U8.2 (K)
/VBIAS-: C30.2, R31.2, R35.2, R37.1, U9.3 (A)
/VIN: C17.1, C33.1, D4.1 (K), FB2.1, L1.1, R29.2, SW3.2 (B), U7.6 (VIN)
/VIN_SENSE: C36.2, R29.1, U4.26 (RB5)
/VOS1: C23.1, R2.2, R10.2
/VOS2: C8.1, R14.2, R15.2
/VSW: C25.2, C26.2, L1.2, R39.1, U7.1 (SW)
GND: C1.1, C5.2, C9.2, C11.2, C12.2, C14.2, C16.2, C17.2, C18.2, C19.2, C20.2, C21.2, C22.2, C24.2, C28.1, C30.1, C33.2, C34.2, C35.1, C36.1, D3.2 (K), D4.2 (A), J3.3, J8.1, NT1.2, Q1.5 (S), R1.2, R22.2, R34.1, R40.2, SW1.2, SW2.2, SW3.MP, U1.7, U2.2 (-VS), U3.3 (GND), U4.8 (VSS), U4.19 (VSS), U5.4 (V-), U6.3 (GND), U7.2 (GND), U9.2 (K)
GNDREF: C2.2, C8.2, C10.2, C11.1, C13.2, C14.1, C15.2, C16.1, C23.2, C31.2, C32.2, J1.1, J2.1, J4.1, J5.1, J6.2 (Ext), R3.1, R7.2, R12.1, R16.2, R26.2, U1.1, U3.5 (D)
unnamed: C1.2, Q1.2 (S), R4.2
unnamed: C2.1, R2.1, R3.2, U2.4
unnamed: C3.1, Q1.4 (D), Q1.6 (D)
unnamed: C4.1, R5.1, U2.1
unnamed: C4.2, R6.1, U2.8
unnamed: C6.1, C7.1, R13.1, U5.3 (+)
unnamed: C6.2, U3.6 (S2)
unnamed: C7.2, U3.4 (S1)
unnamed: C25.1, D2.3 (common)
unnamed: C26.1, D3.3 (common)
unnamed: C27.1, D2.2 (K), R30.1
unnamed: C28.2, D3.1 (A), R31.1
unnamed: C31.1, R36.1, U1.2
unnamed: C32.1, R37.2, U1.6
unnamed: C35.2, R39.2
unnamed: D1.2 (RK), R28.1
unnamed: D1.3 (GK), R25.1
unnamed: D1.4 (BK), R27.1
unnamed: FB2.2, J7.1, J8.2
unnamed: J6.1 (In), R20.1
unnamed: J7.2, NT1.1
unnamed: R7.1, R8.2, U2.5
unnamed: R12.2, U4.2 (RA0)
unnamed: R9.1, R13.2, R38.2, RV1.1, RV1.2, U2.6
unnamed: R14.1, R16.1, R17.2, R18.2, U5.2 (-)
unnamed: R17.1, U6.4 (S1)
unnamed: R18.1, U6.6 (S2)
unnamed: R19.1, R20.2, U5.1, U6.5 (D)
unnamed: R21.2, R22.1, U7.4 (VFB)
unnamed: R26.1, U5.6 (-), U5.7
unnamed: R32.2, R33.1, U8.1 (FB)
unnamed: R34.2, R35.1, U9.1 (FB)
unnamed: R8.1, R38.1, RV1.3

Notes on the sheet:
Gain of 1.006 Gain of 4.049
offset range (+-): 1.4mV Amp 20mV Sensor 23mV field nulling (2 gauss) 44.4mV total
Offset Voltage of +-10mV
Sensor reads 7.3mV/G - 11.42mV/G This includes self heating (50C nominal) Flux concentrator is 1.32G/A typical (+-20% ?) Gain of 32.4 - 13.8 V/V Gain of 21.14 nominal
On resistance of 3 Ohms
PIC Opamps

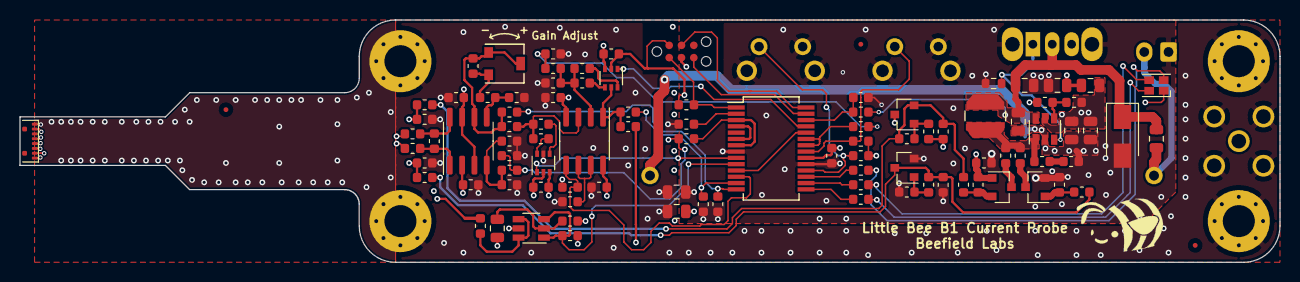
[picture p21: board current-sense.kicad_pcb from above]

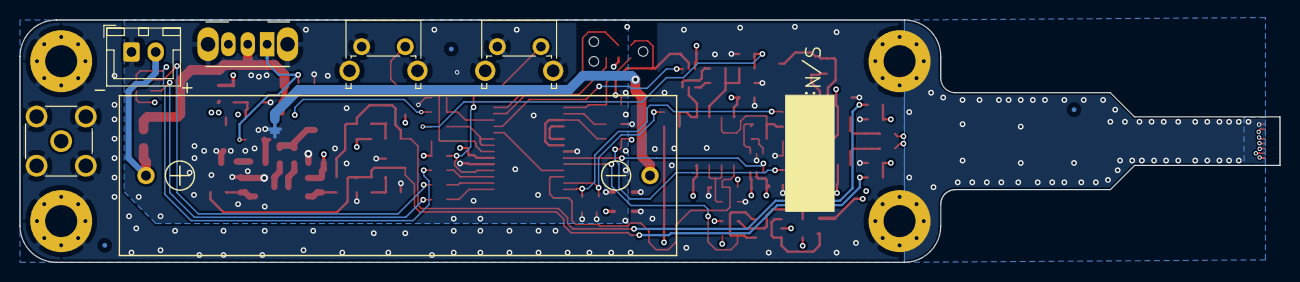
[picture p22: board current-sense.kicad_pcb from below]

Board: 4 copper layers, 130.0 x 25.0 mm, 106 parts (7 on the bottom side), 66 nets.

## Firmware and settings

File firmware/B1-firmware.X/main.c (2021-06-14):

/**
  Generated Main Source File

  Company:
    Microchip Technology Inc.

  File Name:
    main.c

  Summary:
    This is the main file generated using PIC10 / PIC12 / PIC16 / PIC18 MCUs

  Description:
    This header file provides implementations for driver APIs for all modules selected in the GUI.
    Generation Information :
        Product Revision  :  PIC10 / PIC12 / PIC16 / PIC18 MCUs - 1.81.3
        Device            :  PIC16F1776
        Driver Version    :  2.00
*/

/*
    (c) 2018 Microchip Technology Inc. and its subsidiaries. 
    
    Subject to your compliance with these terms, you may use Microchip software and any 
    derivatives exclusively with Microchip products. It is your responsibility to comply with third party 
    license terms applicable to your use of third party software (including open source software) that 
    may accompany Microchip software.
    
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
    IN NO EVENT WILL MICROCHIP BE LIABLE FOR ANY INDIRECT, SPECIAL, PUNITIVE, 
    INCIDENTAL OR CONSEQUENTIAL LOSS, DAMAGE, COST OR EXPENSE OF ANY KIND 
    WHATSOEVER RELATED TO THE SOFTWARE, HOWEVER CAUSED, EVEN IF MICROCHIP 
    HAS BEEN ADVISED OF THE POSSIBILITY OR THE DAMAGES ARE FORESEEABLE. TO 
    THE FULLEST EXTENT ALLOWED BY LAW, MICROCHIP'S TOTAL LIABILITY ON ALL 
    CLAIMS IN ANY WAY RELATED TO THIS SOFTWARE WILL NOT EXCEED THE AMOUNT 
    OF FEES, IF ANY, THAT YOU HAVE PAID DIRECTLY TO MICROCHIP FOR THIS 
    SOFTWARE.
*/

#include "mcc_generated_files/mcc.h"

/*
                         Main application
 */

//led states as (R,G,B)
#define LED_OFF 0x0

#define LED_GREEN 0x2
#define LED_BLUE 0x1
#define LED_RED 0x4

#define LED_CYAN (LED_BLUE | LED_GREEN)
#define LED_PURPLE (LED_BLUE | LED_RED)
#define LED_YELLOW (LED_RED | LED_GREEN)

#define LED_WHITE (LED_GREEN | LED_BLUE | LED_RED)

#define HIGH_FVR_VOLTAGE 460 
//if 4.096V FVR reads too high supply is too low 2^10*2.048/5.012/0.91

#define ADC_SUPERSAMPLE 8

#define ADC_MAX_VAL 262144

uint8_t mux_state = 0;
uint8_t led_color_state = LED_OFF;

//function prototypes

void set_led(uint8_t);
void init_sensor(void);
void reset_sensor(void);

//change state
void SW2_ISR(void){
    
    switch(mux_state){
        case 0: //low gain, high bandwidth 
            led_color_state = LED_GREEN;
            MUX_SEL1_LAT = 1; //bandwidth select
            MUX_SEL2_LAT = 1; //gain select
        break;
        
        case 1: //low gain, low bandwidth 
            led_color_state = LED_YELLOW;
            MUX_SEL1_LAT = 0; //bandwidth select
            MUX_SEL2_LAT = 1; //gain select
        break;
        
        case 2: // high gain, high bandwidth 
            led_color_state = LED_BLUE;
            MUX_SEL1_LAT = 1; //bandwidth select
            MUX_SEL2_LAT = 0; //gain select
        break;
        
        case 3: //high gain, low bandwidth 
            led_color_state = LED_CYAN;
            MUX_SEL1_LAT = 0; //bandwidth select
            MUX_SEL2_LAT = 0; //gain select
        break;
    }
    if(~LED_B_LAT && LED_G_LAT && LED_R_LAT){
        //led is red due to OC, do not clear
    } else{
        set_led(led_color_state);
    }
    mux_state = (mux_state+1)%4;
    __delay_ms(200); //delay for debounce 
}

//zero system
void SW1_ISR(void){
    
     //flash led at start
    set_led(LED_OFF);
    __delay_ms(200);
    set_led(led_color_state);
    reset_sensor();
    __delay_ms(400);
    if(SW1_GetValue() == 0){
        //if switch is still depressed do a full zero
        init_sensor();
    }
    
    //flash LED at end
    set_led(LED_OFF);
    __delay_ms(200);
    set_led(led_color_state);
    
     //zeroing system may trip over range comparators 
     PIR2bits.C2IF = 0;
     PIR2bits.C1IF = 0;
}

uint32_t average_adc_reading(adc_channel_t read_ch){
    
    uint32_t averaged_val = 0;
    //throw away first value
    averaged_val = ADC_GetConversion(read_ch);
    averaged_val = 0;
    for (int i = 0; i<(1<<ADC_SUPERSAMPLE); i++){
        averaged_val = averaged_val + ADC_GetConversion(read_ch);
    }
    
    return averaged_val;
}

uint32_t average_adc_reading_quick(adc_channel_t read_ch){
    
    uint32_t averaged_val = 0;
    //throw away first value
    averaged_val = ADC_GetConversion(read_ch);
    averaged_val = 0;
    
    for (int i = 0; i<(1<<(ADC_SUPERSAMPLE-4)); i++){
        averaged_val = averaged_val + ADC_GetConversion(read_ch);
    }
    
    return (averaged_val<<4);
}


void set_led(uint8_t led_color) {
//red and blue LED pin mapping flipped    
LED_B_LAT = (~led_color>>2)&1;
LED_G_LAT = (~led_color>>1)&1;
LED_R_LAT = (~led_color)&1;
    
}

void zero_stage_1(void){
    uint32_t gnd_ref_val;
    uint16_t best_dac_val = 0;
    uint16_t best_dac_val_l;
    uint32_t stage_val;
    int32_t best_val = ADC_MAX_VAL; 
    int32_t diff_value;
    
    uint16_t start_dac;
    uint16_t end_dac;
    
    uint8_t old_bw = MUX_SEL1_LAT;
    uint8_t old_gain = MUX_SEL2_LAT;
    
    //switch gain to low gain
    MUX_SEL2_LAT = 1;
        //switch bw to low 
    MUX_SEL1_LAT = 0;
    
        
    //initial ranging 
    DAC1_Load10bitInputData(512);
     __delay_ms(20);
     gnd_ref_val = average_adc_reading(GNDREF_SENSE);

    stage_val = average_adc_reading(STAGE2_MON);
    diff_value = (int32_t) stage_val - (int32_t) gnd_ref_val;
    
    if(diff_value > ((1<<ADC_SUPERSAMPLE)*50)){ //250mV
        start_dac = 16;
        end_dac = 512;
    }
    else if (diff_value < ((1<<ADC_SUPERSAMPLE)*(-50)) ){ //-250mv 
        start_dac = 512;
        end_dac = 1007;
    }
    else{
        start_dac = 255;
        end_dac = 768;
    }
    
    DAC1_Load10bitInputData(start_dac);
    __delay_ms(20);
    
    stage_val = average_adc_reading(STAGE2_MON);
    diff_value = (int32_t) stage_val - (int32_t) gnd_ref_val;
    
    for(uint16_t i = start_dac; i<end_dac; i++){
        
        DAC1_Load10bitInputData(i);
        if(i%10==0){ 
            gnd_ref_val = average_adc_reading_quick(GNDREF_SENSE);
        } 
        stage_val = average_adc_reading_quick(STAGE2_MON);
        diff_value = (int32_t) stage_val - (int32_t) gnd_ref_val;
        if (labs(diff_value)<= labs(best_val)){
            best_val = diff_value;
            best_dac_val = i;
        }
  
        //break if diff value is greater than 25mv
        if((diff_value > (1<<ADC_SUPERSAMPLE)*5) && (i > start_dac+10) ){
            break;
        }
    }
    
    DAC1_Load10bitInputData(best_dac_val);
    __delay_ms(50);
    //ramp up 
    gnd_ref_val = average_adc_reading(GNDREF_SENSE);
    best_val = ADC_MAX_VAL;
    start_dac = best_dac_val - 15;
    end_dac = best_dac_val + 15;
    DAC1_Load10bitInputData(start_dac);
    __delay_ms(100);
    for(uint16_t i = start_dac; i<end_dac; i++){
        
        DAC1_Load10bitInputData(i);
        stage_val = average_adc_reading(STAGE2_MON);
        __delay_ms(2);
        diff_value = (int32_t) stage_val - (int32_t) gnd_ref_val;
        if (labs(diff_value)<= labs(best_val)){
            best_val = diff_value;
            best_dac_val = i;
        }
    }
    
    //ramp down 
    best_dac_val_l = best_dac_val;
    best_val = ADC_MAX_VAL;
    
    for(uint16_t i = end_dac; i> start_dac; i--){
        
        DAC1_Load10bitInputData(i);
        stage_val = average_adc_reading(STAGE2_MON);
        __delay_ms(2);
        diff_value = (int32_t) stage_val - (int32_t) gnd_ref_val;
        if (labs(diff_value)<= labs(best_val)){
            best_val = diff_value;
            best_dac_val = i;
        }
    }
    
    //set new DAC value and restore old settings
    best_dac_val = (best_dac_val + best_dac_val_l)>>1;   
    DAC1_Load10bitInputData(best_dac_val);
    MUX_SEL1_LAT = old_bw;
    MUX_SEL2_LAT = old_gain;
}



void zero_stage_2(void){
    uint32_t gnd_ref_val;
    uint16_t best_dac_val = 0;
    uint32_t stage_val;
    uint16_t best_dac_val_l;

    uint8_t old_gain = MUX_SEL2_LAT;
    uint8_t old_bw = MUX_SEL1_LAT;
    
    int32_t best_val = ADC_MAX_VAL; 
    int32_t diff_value;
    
    uint16_t start_dac;
    uint16_t end_dac;
    
    //switch gain to high gain
    MUX_SEL2_LAT = 0;
    //switch bw to low 
    MUX_SEL1_LAT = 0;
    
    //initial ranging 
    DAC5_Load10bitInputData(512);
     __delay_ms(20);
     gnd_ref_val = average_adc_reading(GNDREF_SENSE);

    stage_val = average_adc_reading(STAGE2_MON);
    diff_value = (int32_t) stage_val - (int32_t) gnd_ref_val;
    
    if(diff_value < ((1<<ADC_SUPERSAMPLE)*-8)){ //40mV
        start_dac = 16;
        end_dac = 512;
    }
    else if (diff_value > ((1<<ADC_SUPERSAMPLE)*8) ){ //-40mv 
        start_dac = 512;
        end_dac = 1007;
    }
    else{
        start_dac = 255;
        end_dac = 768;
    }
    
    //rough ramp
    DAC5_Load10bitInputData(start_dac);
    __delay_ms(20);
    
    stage_val = average_adc_reading(STAGE2_MON);
    diff_value = (int32_t) stage_val - (int32_t) gnd_ref_val;
    
    for(uint16_t i = start_dac; i<end_dac; i++){
        
        DAC5_Load10bitInputData(i);
        if(i%10==0){
            gnd_ref_val = average_adc_reading_quick(GNDREF_SENSE);
        }
        
        stage_val = average_adc_reading_quick(STAGE2_MON);
        diff_value = (int32_t) stage_val - (int32_t) gnd_ref_val;
        if (labs(diff_value)<= labs(best_val)){
            best_val = diff_value;
            best_dac_val = i;
        }
      
        //break if diff value is greater than 20mv
        if((diff_value < (1<<ADC_SUPERSAMPLE)*(-4)) && (i > start_dac+10)){
            break;
        }
    }
    
    //ramp up 
    DAC5_Load10bitInputData(best_dac_val);
    __delay_ms(50);

    gnd_ref_val = average_adc_reading(GNDREF_SENSE);
    best_val = ADC_MAX_VAL;
    start_dac = best_dac_val - 15;
    end_dac = best_dac_val + 15;
    DAC5_Load10bitInputData(start_dac);
    __delay_ms(100);
    for(uint16_t i = start_dac; i<end_dac; i++){
        
        DAC5_Load10bitInputData(i);
        stage_val = average_adc_reading(STAGE2_MON);
        __delay_ms(3);
        diff_value = (int32_t) stage_val - (int32_t) gnd_ref_val;
        if (labs(diff_value)<= labs(best_val)){
            best_val = diff_value;
            best_dac_val = i;
        }
    }
    
    //dac ramp down 
    best_dac_val_l = best_dac_val;
    best_val = ADC_MAX_VAL;
    
    for(uint16_t i = end_dac; i> start_dac; i--){
        
        DAC5_Load10bitInputData(i);
        stage_val = average_adc_reading(STAGE2_MON);
        __delay_ms(3);
        diff_value = (int32_t) stage_val - (int32_t) gnd_ref_val;
        if (labs(diff_value)<= labs(best_val)){
            best_val = diff_value;
            best_dac_val = i;
        }
    }
    
    //set new DAC value and restore all settings 
    best_dac_val = (best_dac_val + best_dac_val_l)>>1;        
    DAC5_Load10bitInputData(best_dac_val);
    MUX_SEL1_LAT = old_bw;
    MUX_SEL2_LAT = old_gain;
}

void init_sensor(void){
    uint32_t gnd_ref_val;
    uint32_t stage_val;
    int32_t diff_value;
    
    __delay_ms(5);
    zero_stage_1();
    //only zero second stage if in use
    if(MUX_SEL2_LAT == 0){
        __delay_ms(50);
        zero_stage_2();
    }
    
    stage_val = average_adc_reading(STAGE2_MON);
    gnd_ref_val = average_adc_reading(GNDREF_SENSE);
    diff_value = (int32_t) gnd_ref_val - (int32_t) stage_val ;
    if ( labs(diff_value) > ((1<<ADC_SUPERSAMPLE)*20) ){ //100mV offset
        set_led(LED_RED);
        __delay_ms(3000);
        set_led(led_color_state);
    }
}

void reset_sensor(){
    SR_SetLow();
     __delay_ms(40);
    SR_SetHigh();
     __delay_ms(40);
    SR_SetLow();
    __delay_ms(50);
}

void low_battery_loop(){
    while(1){
        set_led(LED_OFF);
        
        __delay_ms(500);
        
        set_led(LED_RED);
        
        __delay_ms(500);
    }
}
void main(void)
{
    // initialize the device
    SYSTEM_Initialize();
    
    DAC7_SetOutput(16); //set virtual ground to ~2.5V
    DAC3_SetOutput(25); //set overload high comparator  
    DAC4_SetOutput(7); //set overload low comparator 
    
    //init offset dac
    DAC5_Load10bitInputData(512);
    DAC1_Load10bitInputData(512);
    __delay_ms(50);
    
    //absolute field sensing / debug mode
    if((SW1_GetValue() == 0) && (SW2_GetValue() == 0)){
        set_led(LED_PURPLE);
        while(1){
            SR_SetLow();
            __delay_ms(9);
            SR_SetHigh();
            __delay_ms(9);
        }
    }
    
    led_color_state = LED_GREEN;
    mux_state = 0;
    SW2_ISR();//initialize LED and mux
    reset_sensor();
    __delay_ms(100); 
    zero_stage_1();
    __delay_ms(50);
    zero_stage_2();
    //zeroing system may trip over range comparators 
    PIR2bits.C2IF = 0;
    PIR2bits.C1IF = 0;
    //set interrupt handler for SW2
    IOCBF0_SetInterruptHandler(SW2_ISR);
    //set interrupt handler for SW1
    IOCCF7_SetInterruptHandler(SW1_ISR); 
    set_led(LED_OFF);
    __delay_ms(200);
    set_led(led_color_state);
    INTERRUPT_GlobalInterruptEnable();
    INTERRUPT_PeripheralInterruptEnable();
    
    while (1)
    {
        __delay_ms(500);
        if((average_adc_reading(channel_FVRBuffer1)>>ADC_SUPERSAMPLE) > HIGH_FVR_VOLTAGE){
            INTERRUPT_GlobalInterruptDisable();
            INTERRUPT_PeripheralInterruptDisable();
            low_battery_loop();
        }
    }
}
/**
 End of File
*/

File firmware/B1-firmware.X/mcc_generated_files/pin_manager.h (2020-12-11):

/**
  @Generated Pin Manager Header File

  @Company:
    Microchip Technology Inc.

  @File Name:
    pin_manager.h

  @Summary:
    This is the Pin Manager file generated using PIC10 / PIC12 / PIC16 / PIC18 MCUs

  @Description
    This header file provides APIs for driver for .
    Generation Information :
        Product Revision  :  PIC10 / PIC12 / PIC16 / PIC18 MCUs - 1.81.3
        Device            :  PIC16F1776
        Driver Version    :  2.11
    The generated drivers are tested against the following:
        Compiler          :  XC8 2.20 and above
        MPLAB 	          :  MPLAB X 5.40	
*/

/*
    (c) 2018 Microchip Technology Inc. and its subsidiaries. 
    
    Subject to your compliance with these terms, you may use Microchip software and any 
    derivatives exclusively with Microchip products. It is your responsibility to comply with third party 
    license terms applicable to your use of third party software (including open source software) that 
    may accompany Microchip software.
    
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
    IN NO EVENT WILL MICROCHIP BE LIABLE FOR ANY INDIRECT, SPECIAL, PUNITIVE, 
    INCIDENTAL OR CONSEQUENTIAL LOSS, DAMAGE, COST OR EXPENSE OF ANY KIND 
    WHATSOEVER RELATED TO THE SOFTWARE, HOWEVER CAUSED, EVEN IF MICROCHIP 
    HAS BEEN ADVISED OF THE POSSIBILITY OR THE DAMAGES ARE FORESEEABLE. TO 
    THE FULLEST EXTENT ALLOWED BY LAW, MICROCHIP'S TOTAL LIABILITY ON ALL 
    CLAIMS IN ANY WAY RELATED TO THIS SOFTWARE WILL NOT EXCEED THE AMOUNT 
    OF FEES, IF ANY, THAT YOU HAVE PAID DIRECTLY TO MICROCHIP FOR THIS 
    SOFTWARE.
*/

#ifndef PIN_MANAGER_H
#define PIN_MANAGER_H

/**
  Section: Included Files
*/

#include <xc.h>

#define INPUT   1
#define OUTPUT  0

#define HIGH    1
#define LOW     0

#define ANALOG      1
#define DIGITAL     0

#define PULL_UP_ENABLED      1
#define PULL_UP_DISABLED     0

// get/set GNDREF_SENSE aliases
#define GNDREF_SENSE_TRIS                 TRISAbits.TRISA0
#define GNDREF_SENSE_LAT                  LATAbits.LATA0
#define GNDREF_SENSE_PORT                 PORTAbits.RA0
#define GNDREF_SENSE_WPU                  WPUAbits.WPUA0
#define GNDREF_SENSE_OD                   ODCONAbits.ODA0
#define GNDREF_SENSE_ANS                  ANSELAbits.ANSA0
#define GNDREF_SENSE_SetHigh()            do { LATAbits.LATA0 = 1; } while(0)
#define GNDREF_SENSE_SetLow()             do { LATAbits.LATA0 = 0; } while(0)
#define GNDREF_SENSE_Toggle()             do { LATAbits.LATA0 = ~LATAbits.LATA0; } while(0)
#define GNDREF_SENSE_GetValue()           PORTAbits.RA0
#define GNDREF_SENSE_SetDigitalInput()    do { TRISAbits.TRISA0 = 1; } while(0)
#define GNDREF_SENSE_SetDigitalOutput()   do { TRISAbits.TRISA0 = 0; } while(0)
#define GNDREF_SENSE_SetPullup()          do { WPUAbits.WPUA0 = 1; } while(0)
#define GNDREF_SENSE_ResetPullup()        do { WPUAbits.WPUA0 = 0; } while(0)
#define GNDREF_SENSE_SetPushPull()        do { ODCONAbits.ODA0 = 0; } while(0)
#define GNDREF_SENSE_SetOpenDrain()       do { ODCONAbits.ODA0 = 1; } while(0)
#define GNDREF_SENSE_SetAnalogMode()      do { ANSELAbits.ANSA0 = 1; } while(0)
#define GNDREF_SENSE_SetDigitalMode()     do { ANSELAbits.ANSA0 = 0; } while(0)

// get/set RA1 procedures
#define RA1_SetHigh()            do { LATAbits.LATA1 = 1; } while(0)
#define RA1_SetLow()             do { LATAbits.LATA1 = 0; } while(0)
#define RA1_Toggle()             do { LATAbits.LATA1 = ~LATAbits.LATA1; } while(0)
#define RA1_GetValue()              PORTAbits.RA1
#define RA1_SetDigitalInput()    do { TRISAbits.TRISA1 = 1; } while(0)
#define RA1_SetDigitalOutput()   do { TRISAbits.TRISA1 = 0; } while(0)
#define RA1_SetPullup()             do { WPUAbits.WPUA1 = 1; } while(0)
#define RA1_ResetPullup()           do { WPUAbits.WPUA1 = 0; } while(0)
#define RA1_SetAnalogMode()         do { ANSELAbits.ANSA1 = 1; } while(0)
#define RA1_SetDigitalMode()        do { ANSELAbits.ANSA1 = 0; } while(0)

// get/set RA2 procedures
#define RA2_SetHigh()            do { LATAbits.LATA2 = 1; } while(0)
#define RA2_SetLow()             do { LATAbits.LATA2 = 0; } while(0)
#define RA2_Toggle()             do { LATAbits.LATA2 = ~LATAbits.LATA2; } while(0)
#define RA2_GetValue()              PORTAbits.RA2
#define RA2_SetDigitalInput()    do { TRISAbits.TRISA2 = 1; } while(0)
#define RA2_SetDigitalOutput()   do { TRISAbits.TRISA2 = 0; } while(0)
#define RA2_SetPullup()             do { WPUAbits.WPUA2 = 1; } while(0)
#define RA2_ResetPullup()           do { WPUAbits.WPUA2 = 0; } while(0)
#define RA2_SetAnalogMode()         do { ANSELAbits.ANSA2 = 1; } while(0)
#define RA2_SetDigitalMode()        do { ANSELAbits.ANSA2 = 0; } while(0)

// get/set RA4 procedures
#define RA4_SetHigh()            do { LATAbits.LATA4 = 1; } while(0)
#define RA4_SetLow()             do { LATAbits.LATA4 = 0; } while(0)
#define RA4_Toggle()             do { LATAbits.LATA4 = ~LATAbits.LATA4; } while(0)
#define RA4_GetValue()              PORTAbits.RA4
#define RA4_SetDigitalInput()    do { TRISAbits.TRISA4 = 1; } while(0)
#define RA4_SetDigitalOutput()   do { TRISAbits.TRISA4 = 0; } while(0)
#define RA4_SetPullup()             do { WPUAbits.WPUA4 = 1; } while(0)
#define RA4_ResetPullup()           do { WPUAbits.WPUA4 = 0; } while(0)
#define RA4_SetAnalogMode()         do { ANSELAbits.ANSA4 = 1; } while(0)
#define RA4_SetDigitalMode()        do { ANSELAbits.ANSA4 = 0; } while(0)

// get/set RA5 procedures
#define RA5_SetHigh()            do { LATAbits.LATA5 = 1; } while(0)
#define RA5_SetLow()             do { LATAbits.LATA5 = 0; } while(0)
#define RA5_Toggle()             do { LATAbits.LATA5 = ~LATAbits.LATA5; } while(0)
#define RA5_GetValue()              PORTAbits.RA5
#define RA5_SetDigitalInput()    do { TRISAbits.TRISA5 = 1; } while(0)
#define RA5_SetDigitalOutput()   do { TRISAbits.TRISA5 = 0; } while(0)
#define RA5_SetPullup()             do { WPUAbits.WPUA5 = 1; } while(0)
#define RA5_ResetPullup()           do { WPUAbits.WPUA5 = 0; } while(0)
#define RA5_SetAnalogMode()         do { ANSELAbits.ANSA5 = 1; } while(0)
#define RA5_SetDigitalMode()        do { ANSELAbits.ANSA5 = 0; } while(0)
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

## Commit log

2020-12-11 first release candidate
    [casing-bottom.step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]
2020-12-11 added BOM
    [current-sense.csv]
2020-12-11 changes to gain resistors
    [current-sense-B_Cu.gbl, current-sense-B_Mask.gbs, current-sense-B_Paste.gbp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]
2021-01-25 added magnetics modeling files
    [trace_fields_0_2mm.csv, trace_fields_1_6mm.csv, trace_fields_noground.csv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]
2021-02-01 pre-production PCB assembly
    [current-sense.csv, current-sense.kicad_pcb, current-sense.sch]
2021-02-01 updated gerbers and PDF schematic
    [current-sense-B_Cu.gbl, current-sense-B_Mask.gbs, current-sense-B_Paste.gbp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]
2021-03-04 added plots for magnetic modeling
2021-03-04 PCB MCAD Export
    [casing-bottom.step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]
2021-04-10 production PCB version
    [casing-B_Cu.gbr, casing-B_Mask.gbr, casing-B_SilkS.gbr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]
2021-06-29 added production test data and getting started placeholder
    [A00.CSV, A01.CSV, A02.CSV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]
2023-04-03 updated documentation on mechanical assembly
    [ring_cover_production.stl, tip-cover_production.stl]

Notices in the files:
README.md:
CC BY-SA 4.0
